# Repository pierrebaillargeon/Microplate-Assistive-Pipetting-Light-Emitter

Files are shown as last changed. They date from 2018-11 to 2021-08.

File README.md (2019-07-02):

# Microplate Assistive Pipetting Light Emitter

The contents of this repository represent the design files and code needed to reproduce the electronics, firmware and GUI interface for the Microplate Assistive Pipetting Light Emitter. 

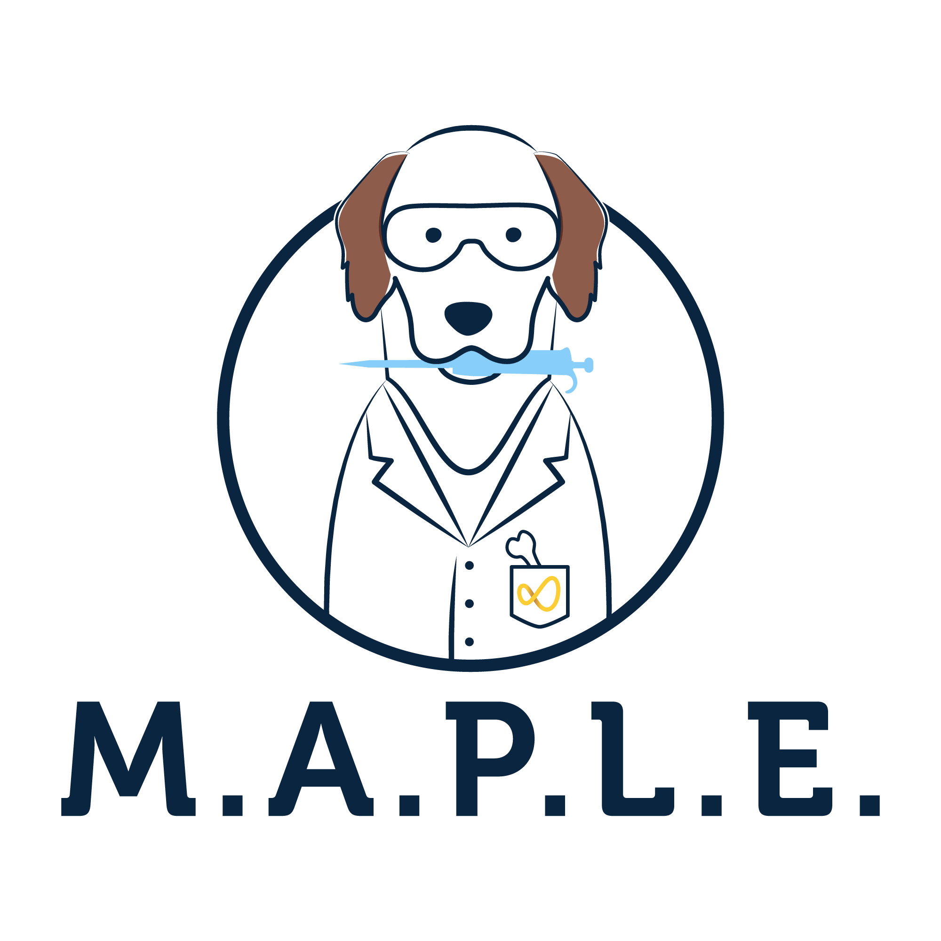
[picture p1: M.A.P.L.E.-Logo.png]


A manuscript describing the design and usage of this light guide has been published in the <A href="https://journals.sagepub.com/doi/full/10.1177/2472630318822476">SLAS Technology journal</A> and presented at SLAS 2019 as part of a presentation titled <A href="https://www.pathlms.com/slas/courses/10547/video_presentations/127546">'A longitudinal analysis over 10 years of enabling technologies for early drug discovery using open source tools'</a>.

If you are interested in purchasing preassembled illumination panels, as opposed to assembling them by hand, they are available on the <a href="https://www.tindie.com/stores/Maplebear/">Maplebear Electronics Tindie store</a>.

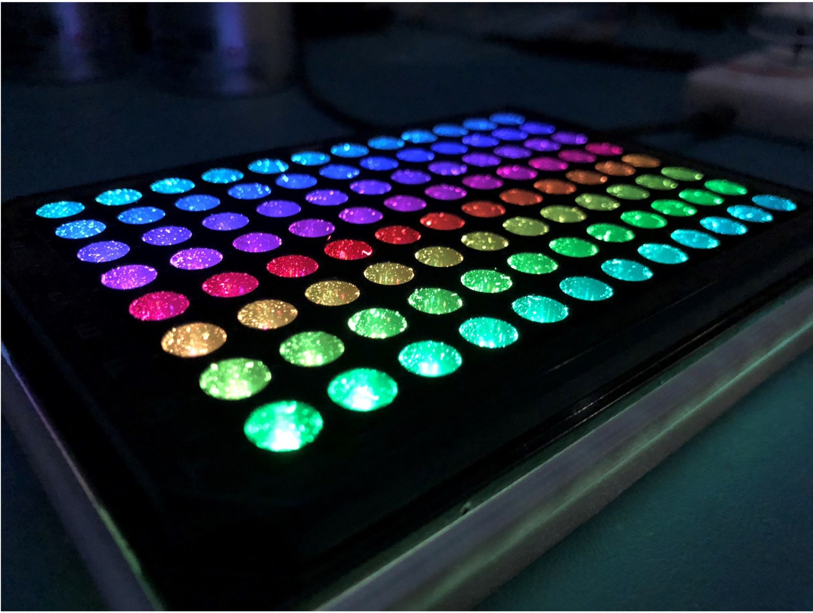
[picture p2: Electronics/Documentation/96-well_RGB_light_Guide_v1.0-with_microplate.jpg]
<A href="https://raw.githubusercontent.com/pierrebaillargeon/Microplate-Assistive-Pipetting-Light-Emitter/master/Electronics/Documentation/96-well_RGB_light_Guide_v1.0-with_m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"></a>
  
<A href="https://raw.githubusercontent.com/pierrebaillargeon/Microplate-Assistive-Pipetting-Light-Emitter/master/Electronics/Documentation/96-well_RGB_light_guide_v1.3-protot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"></a>
  
<A href="https://raw.githubusercontent.com/pierrebaillargeon/Microplate-Assistive-Pipetting-Light-Emitter/master/Electronics/Documentation/384-well_RGB_light_guide_v1.1.png"></a>

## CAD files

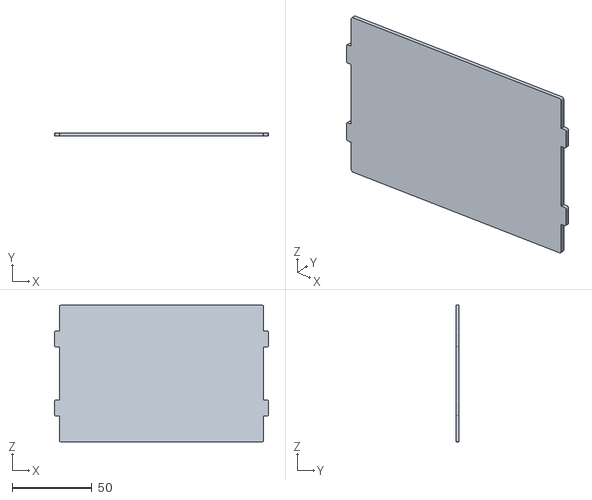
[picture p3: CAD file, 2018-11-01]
CAD/clear-cover.stl
133.8 x 2.00 x 85.5

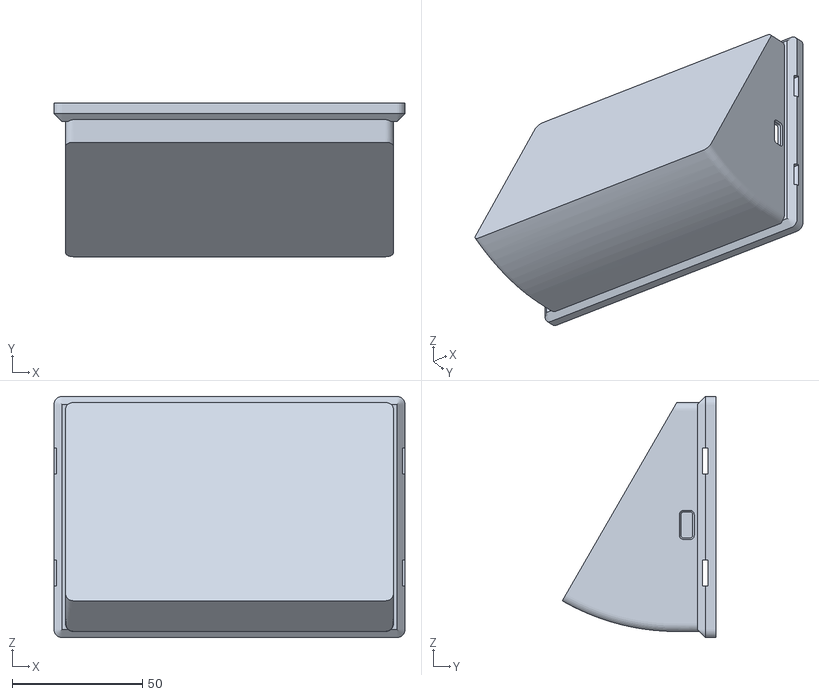
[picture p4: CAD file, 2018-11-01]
CAD/Gen 2 enclosure/30 degree RGB enclosure v2.1.stl
134.9 x 59.0 x 92.6

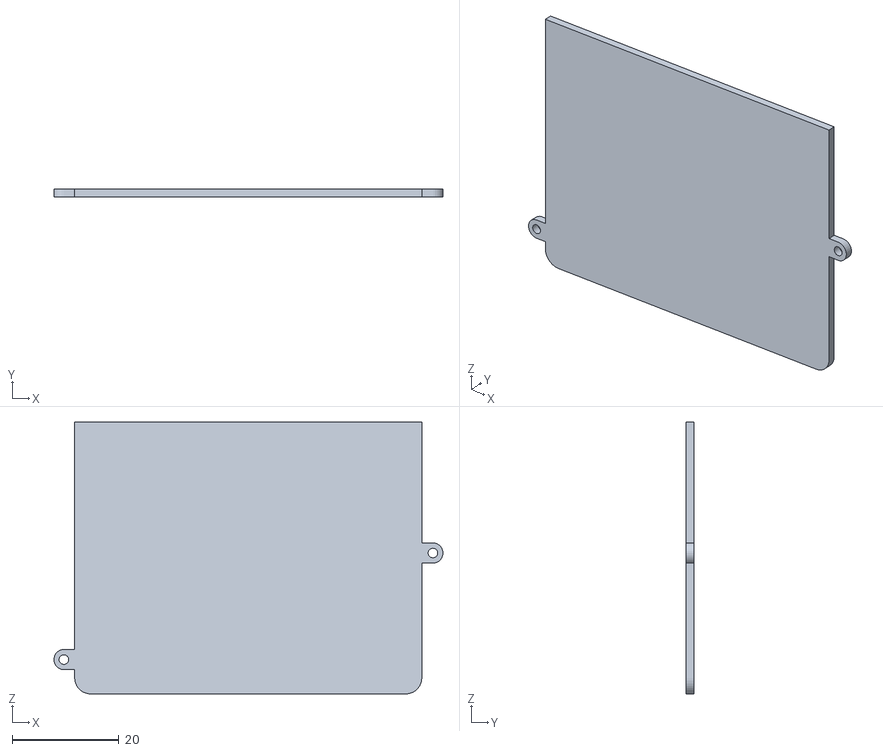
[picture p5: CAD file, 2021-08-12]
CAD/Portable enclosure/Battery lid.stl
72.8 x 1.50 x 50.9

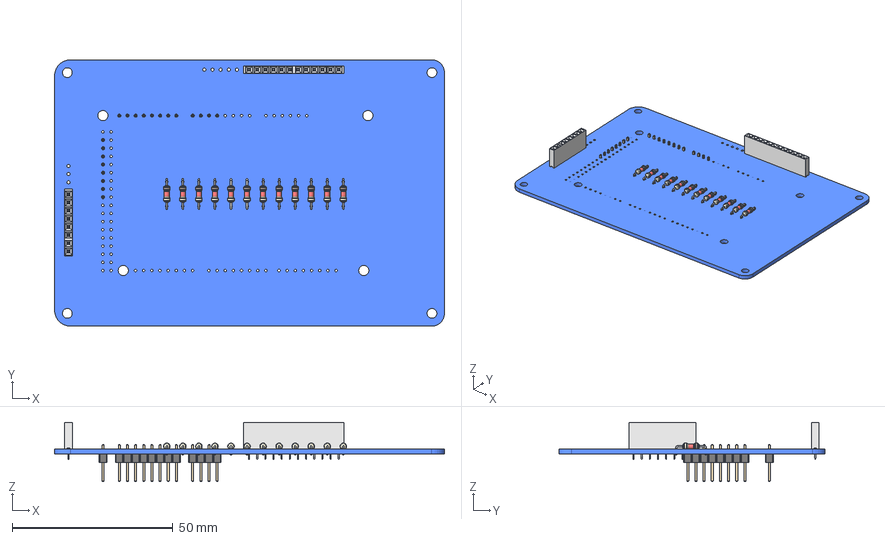
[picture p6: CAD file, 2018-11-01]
Electronics/LED Matrix - 96 well adapter board for Arduino mega/96 well adapter board for Arduino mega1.step
121.5 x 83.0 x 18.4 mm
Pcb
Socket_Strip_Straight_1x12_Pitch2.54mm_
Socket_Strip_Straight_1x08_Pitch2.54mm_
Actual_resistor_
Actual_resistor_001
Actual_resistor_002
Actual_resistor_003
Actual_resistor_004
Actual_resistor_005
Actual_resistor_006
Actual_resistor_007
Actual_resistor_008
Actual_resistor_009
Actual_resistor_010
Actual_resistor_011
Pin_Header_Straight_1x08_Pitch254mm_
Pin_Header_Straight_1x08_Pitch254mm_001
Pin_Header_Straight_1x04_Pitch254mm_

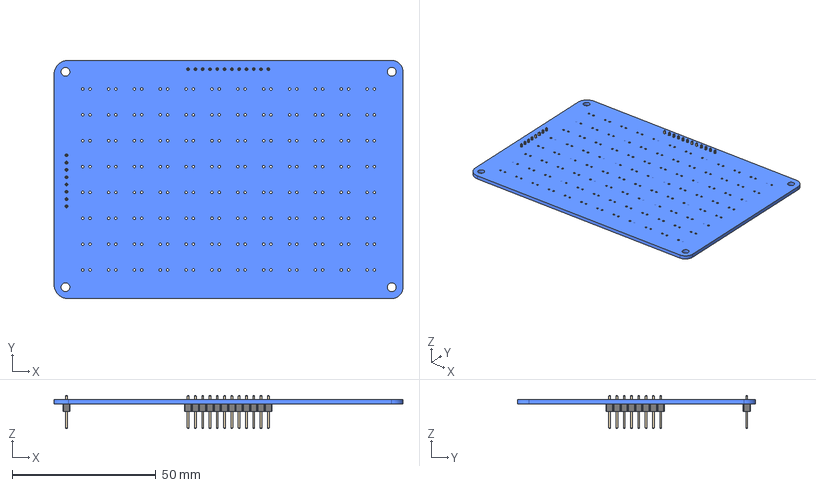
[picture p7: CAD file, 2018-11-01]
Electronics/LED Matrix - 96 well/LED Matrix1.step
121.5 x 83.0 x 11.5 mm
Pcb
Pin_Header_Straight_1x12_Pitch254mm_
Pin_Header_Straight_1x08_Pitch254mm_

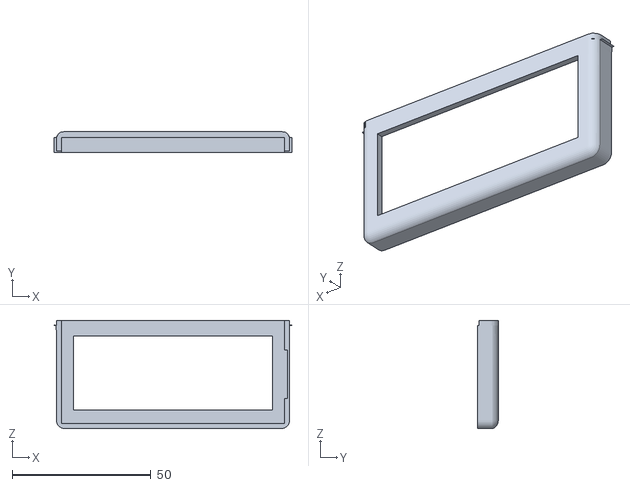
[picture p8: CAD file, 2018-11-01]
CAD/Gen 2 enclosure/LCD cover for enclosure v2.0.stl
85.7 x 7.41 x 38.9

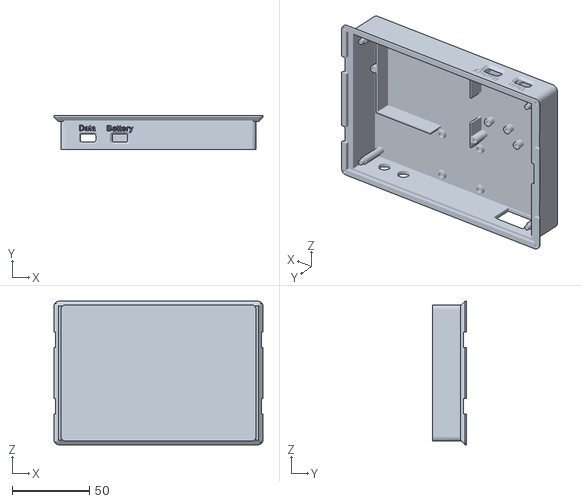
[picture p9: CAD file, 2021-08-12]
CAD/Portable enclosure/Enclosure.stl
134.9 x 22.0 x 92.6

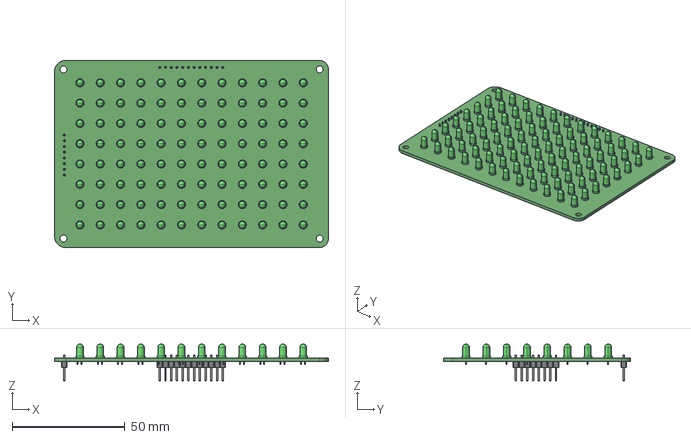
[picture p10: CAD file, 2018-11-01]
Electronics/LED Matrix - 96 well/LED Matrix.step
121.5 x 83.0 x 16.4 mm

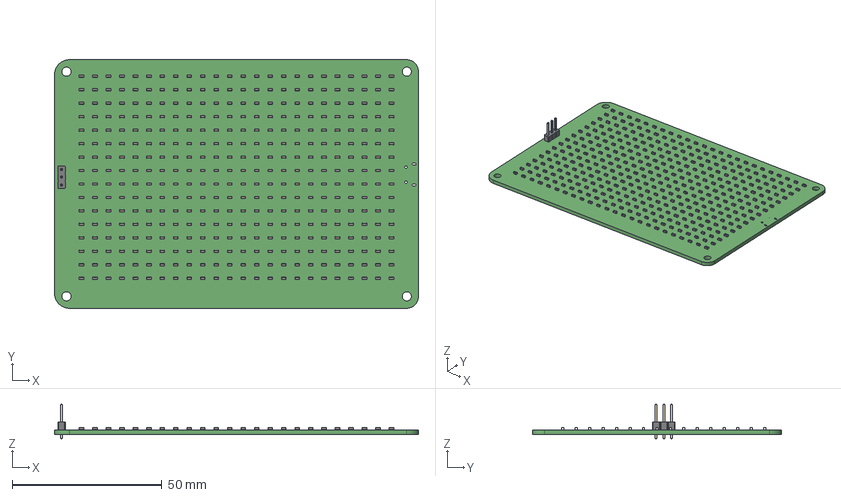
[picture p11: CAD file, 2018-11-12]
Electronics/Neopixel - 384 well/Neopixel nano - 384 well v2.step
121.5 x 83.0 x 11.5 mm

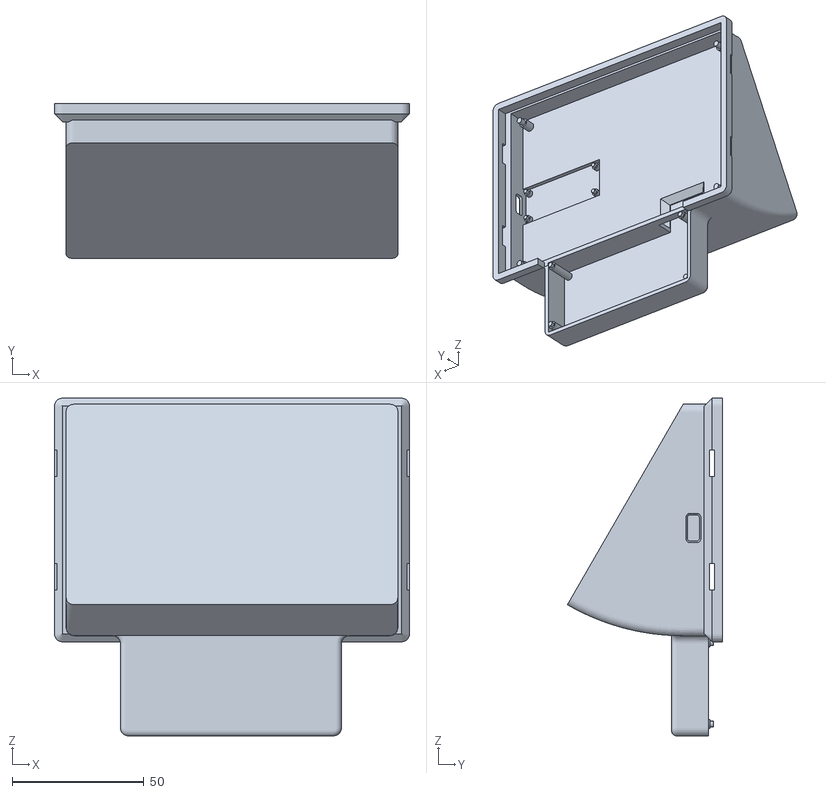
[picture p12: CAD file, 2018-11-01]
CAD/Gen 2 enclosure/Enclosure v2.0 with LCD.stl
134.9 x 59.0 x 128.4

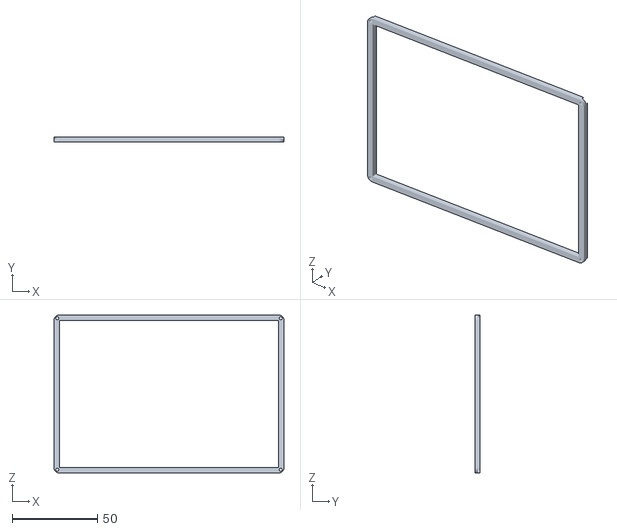
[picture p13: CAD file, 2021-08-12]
CAD/Portable enclosure/Enclosure top lid.stl
134.9 x 3.00 x 92.6

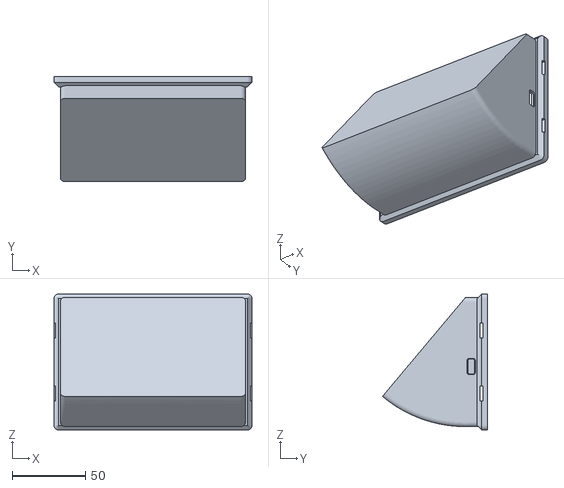
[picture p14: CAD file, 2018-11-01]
CAD/Gen 2 enclosure/40 degree RGB enclosure v2.1.stl
134.9 x 71.6 x 92.6

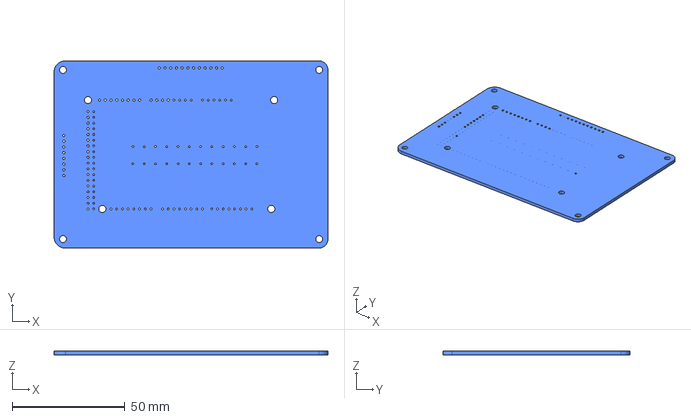
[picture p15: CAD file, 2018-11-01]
Electronics/LED Matrix - 96 well adapter board for Arduino mega/Pcb.step
121.5 x 83.0 x 1.60 mm

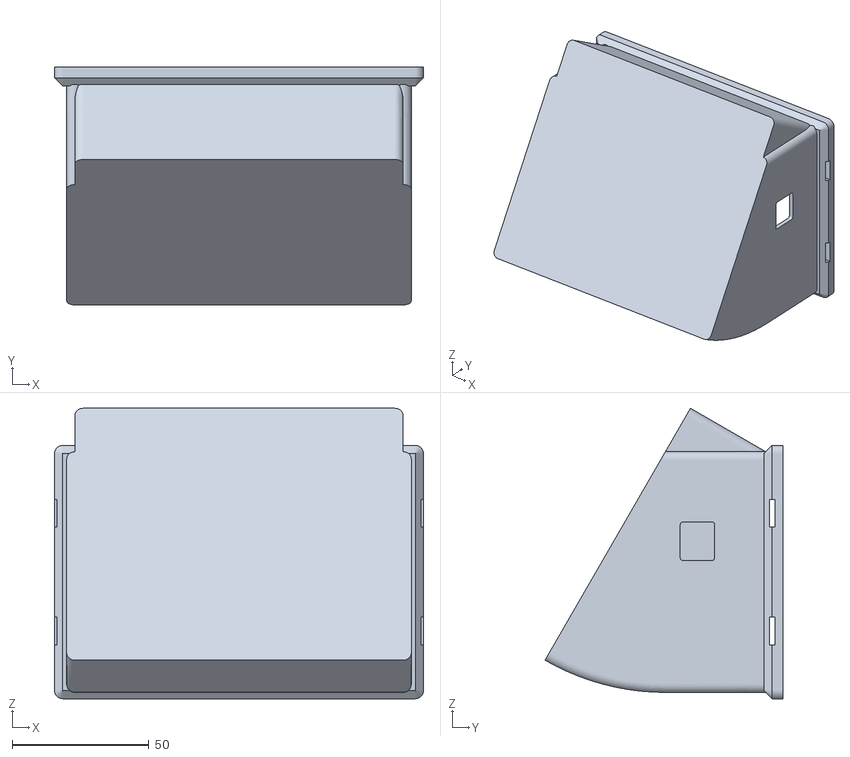
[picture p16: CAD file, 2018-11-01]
CAD/Gen 2 enclosure/30 degree Enclosure v2.1.stl
134.9 x 87.0 x 106.2

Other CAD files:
Electronics/Neopixel - 384 well/Neopixel nano - 384 well.step
Electronics/Neopixel - 96 well/Neopixel mini - 96 well.step
Electronics/LED Matrix - 96 well adapter board for Arduino mega/_6_well_adapter_board_for_Arduino_mega1.FCStd
Electronics/LED Matrix - 96 well adapter board for Arduino mega/_6_well_adapter_board_for_Arduino_mega.FCStd
CAD/Gen 1 enclosure/Enclosure v2.1.stl
CAD/Portable enclosure/PortableEnclosure.f3z
Electronics/LED Matrix - 96 well/LED_Matrix.FCStd
Electronics/LED Matrix - 96 well/LED_Matrix1.FCStd

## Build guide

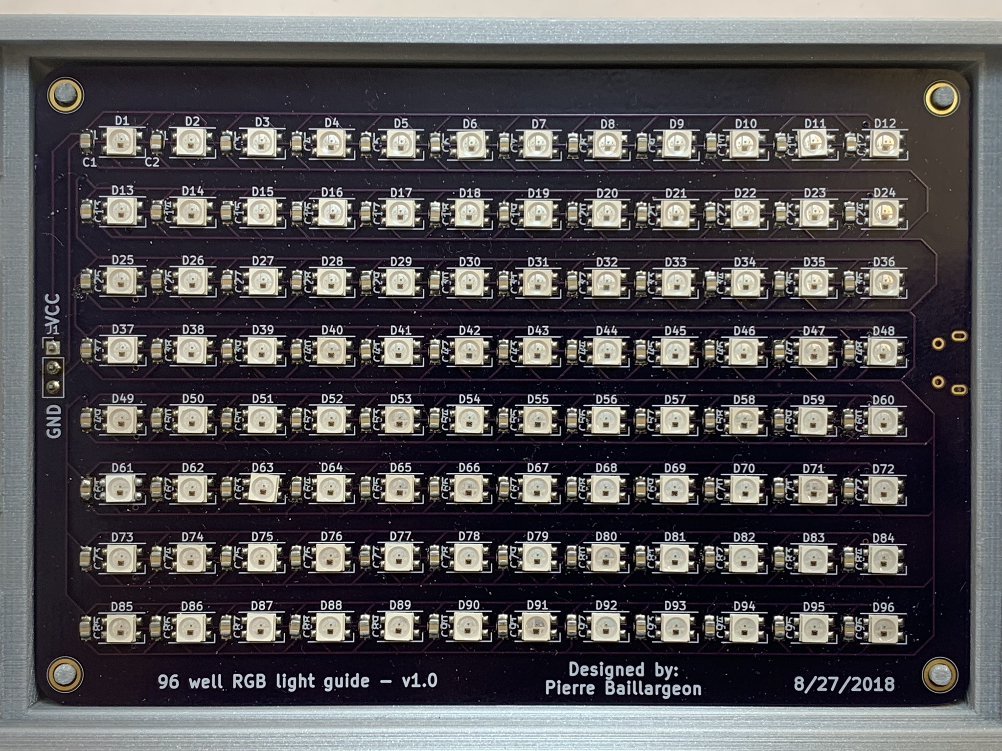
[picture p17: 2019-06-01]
Electronics/Documentation/96-well_RGB_light_guide_v1.0-prototype_PCB.jpg

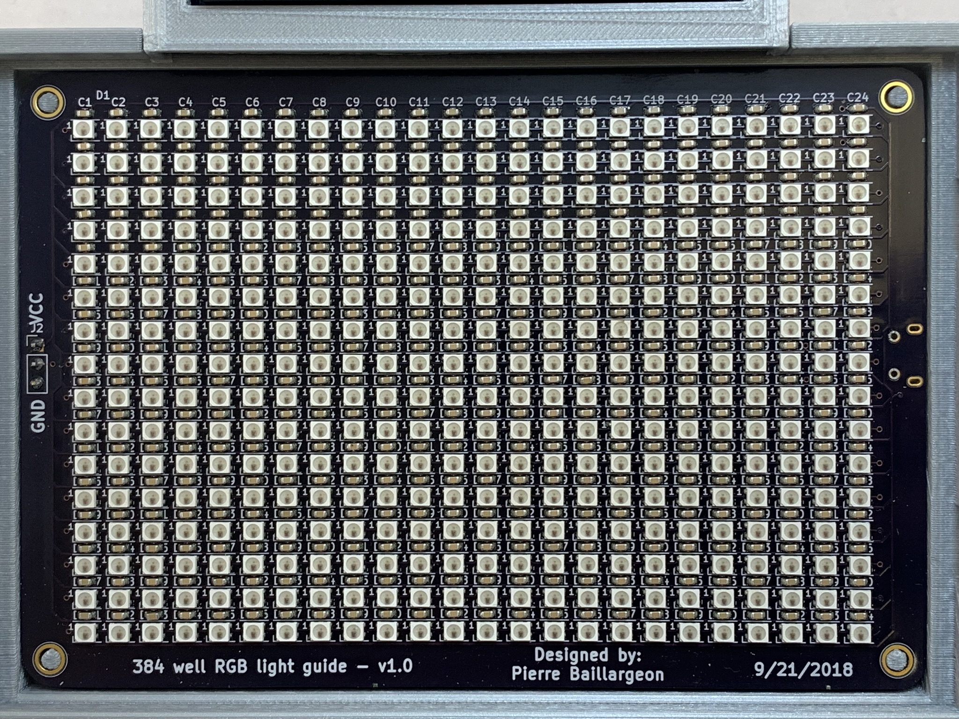
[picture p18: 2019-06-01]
Electronics/Documentation/384-well_RGB_light_guide_v1.0-prototype_PCB.jpg

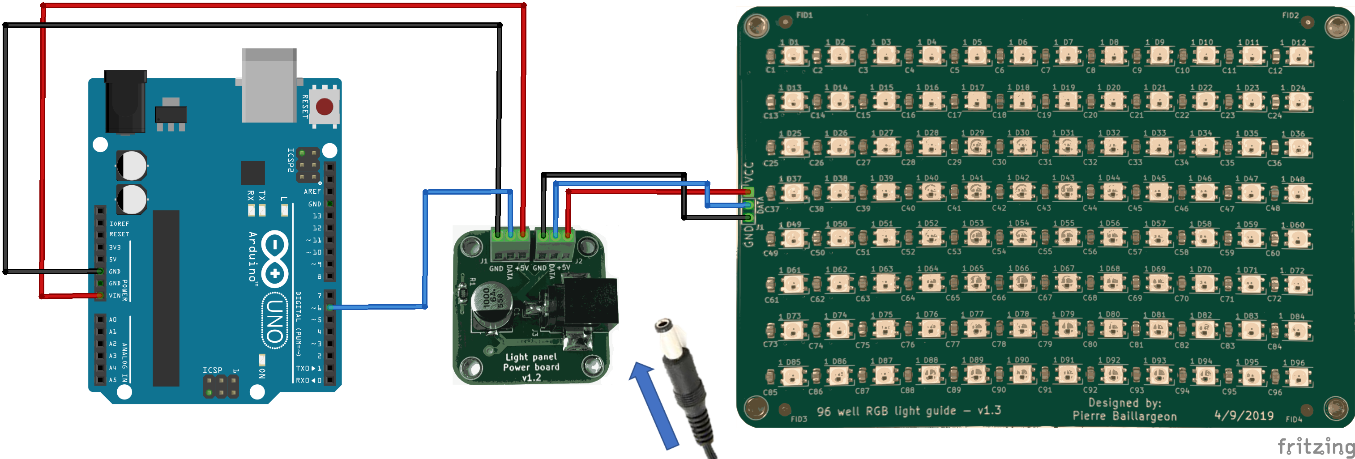
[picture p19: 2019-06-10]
Electronics/Documentation/96-well-rgb-light-guide-wiring-example.png

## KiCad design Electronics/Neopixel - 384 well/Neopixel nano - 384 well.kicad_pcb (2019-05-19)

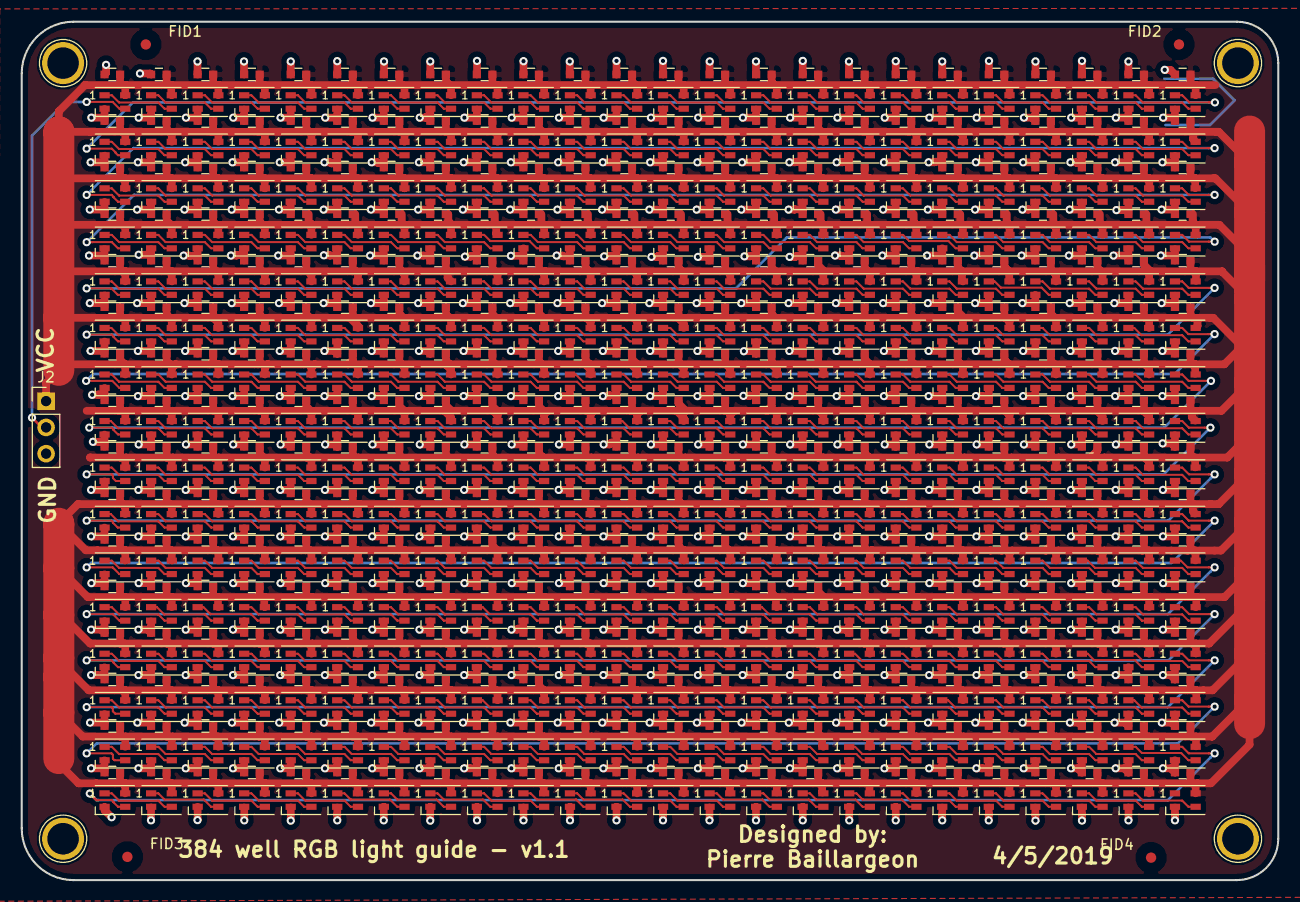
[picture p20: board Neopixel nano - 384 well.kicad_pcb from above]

Board: 2 copper layers, 121.5 x 83.0 mm, 773 parts (0 on the bottom side), 386 nets.

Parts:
C1, C2, C3, C4, C5, C6, C7, C8, C9, C10, C11, C12, C13, C14, C15, C16, C17, C18, C19, C20, C21, C22, C23, C24, C25, C26, C27, C28, C29, C30, C31, C32, C33, C34, C35, C36, C37, C38, C39, C40, C41, C42, C43, C44, C45, C46, C47, C48, C49, C50, C51, C52, C53, C54, C55, C56, C57, C58, C59, C60, C61, C62, C63, C64, C65, C66, C67, C68, C69, C70, C71, C72, C73, C74, C75, C76, C77, C78, C79, C80, C81, C82, C83, C84, C85, C86, C87, C88, C89, C90, C91, C92, C93, C94, C95, C96, C97, C98, C99, C100, C101, C102, C103, C104, C105, C106, C107, C108, C109, C110, C111, C112, C113, C114, C115, C116, C117, C118, C119, C120, C121, C122, C123, C124, C125, C126, C127, C128, C129, C130, C131, C132, C133, C134, C135, C136, C137, C138, C139, C140, C141, C142, C143, C144, C145, C146, C147, C148, C149, C150, C151, C152, C153, C154, C155, C156, C157, C158, C159, C160, C161, C162, C163, C164, C165, C166, C167, C168, C169, C170, C171, C172, C173, C174, C175, C176, C177, C178, C179, C180, C181, C182, C183, C184, C185, C186, C187, C188, C189, C190, C191, C192, C193, C194, C195, C196, C197, C198, C199, C200, C201, C202, C203, C204, C205, C206, C207, C208, C209, C210, C211, C212, C213, C214, C215, C216, C217, C218, C219, C220, C221, C222, C223, C224, C225, C226, C227, C228, C229, C230, C231, C232, C233, C234, C235, C236, C237, C238, C239, C240, C241, C242, C243, C244, C245, C246, C247, C248, C249, C250, C251, C252, C253, C254, C255, C256, C257, C258, C259, C260, C261, C262, C263, C264, C265, C266, C267, C268, C269, C270, C271, C272, C273, C274, C275, C276, C277, C278, C279, C280, C281, C282, C283, C284, C285, C286, C287, C288, C289, C290, C291, C292, C293, C294, C295, C296, C297, C298, C299, C300, C301, C302, C303, C304, C305, C306, C307, C308, C309, C310, C311, C312, C313, C314, C315, C316, C317, C318, C319, C320, C321, C322, C323, C324, C325, C326, C327, C328, C329, C330, C331, C332, C333, C334, C335, C336, C337, C338, C339, C340, C341, C342, C343, C344, C345, C346, C347, C348, C349, C350, C351, C352, C353, C354, C355, C356, C357, C358, C359, C360, C361, C362, C363, C364, C365, C366, C367, C368, C369, C370, C371, C372, C373, C374, C375, C376, C377, C378, C379, C380, C381, C382, C383, C384: CAP; C_0603
D1, D2, D3, D4, D5, D6, D7, D8, D9, D10, D11, D12, D13, D14, D15, D16, D17, D18, D19, D20, D21, D22, D23, D24, D25, D26, D27, D28, D29, D30, D31, D32, D33, D34, D35, D36, D37, D38, D39, D40, D41, D42, D43, D44, D45, D46, D47, D48, D49, D50, D51, D52, D53, D54, D55, D56, D57, D58, D59, D60, D61, D62, D63, D64, D65, D66, D67, D68, D69, D70, D71, D72, D73, D74, D75, D76, D77, D78, D79, D80, D81, D82, D83, D84, D85, D86, D87, D88, D89, D90, D91, D92, D93, D94, D95, D96, D97, D98, D99, D100, D101, D102, D103, D104, D105, D106, D107, D108, D109, D110, D111, D112, D113, D114, D115, D116, D117, D118, D119, D120, D121, D122, D123, D124, D125, D126, D127, D128, D129, D130, D131, D132, D133, D134, D135, D136, D137, D138, D139, D140, D141, D142, D143, D144, D145, D146, D147, D148, D149, D150, D151, D152, D153, D154, D155, D156, D157, D158, D159, D160, D161, D162, D163, D164, D165, D166, D167, D168, D169, D170, D171, D172, D173, D174, D175, D176, D177, D178, D179, D180, D181, D182, D183, D184, D185, D186, D187, D188, D189, D190, D191, D192, D193, D194, D195, D196, D197, D198, D199, D200, D201, D202, D203, D204, D205, D206, D207, D208, D209, D210, D211, D212, D213, D214, D215, D216, D217, D218, D219, D220, D221, D222, D223, D224, D225, D226, D227, D228, D229, D230, D231, D232, D233, D234, D235, D236, D237, D238, D239, D240, D241, D242, D243, D244, D245, D246, D247, D248, D249, D250, D251, D252, D253, D254, D255, D256, D257, D258, D259, D260, D261, D262, D263, D264, D265, D266, D267, D268, D269, D270, D271, D272, D273, D274, D275, D276, D277, D278, D279, D280, D281, D282, D283, D284, D285, D286, D287, D288, D289, D290, D291, D292, D293, D294, D295, D296, D297, D298, D299, D300, D301, D302, D303, D304, D305, D306, D307, D308, D309, D310, D311, D312, D313, D314, D315, D316, D317, D318, D319, D320, D321, D322, D323, D324, D325, D326, D327, D328, D329, D330, D331, D332, D333, D334, D335, D336, D337, D338, D339, D340, D341, D342, D343, D344, D345, D346, D347, D348, D349, D350, D351, D352, D353, D354, D355, D356, D357, D358, D359, D360, D361, D362, D363, D364, D365, D366, D367, D368, D369, D370, D371, D372, D373, D374, D375, D376, D377, D378, D379, D380, D381, D382, D383, D384: SK6805; LED_SK6805_PLCC4_2.4x2.7mm_P1.3mm
FID1, FID2, FID3, FID4: Fiducial_1mm_Mask3mm
J2: Conn_01x03_Male; Pin_Header_Straight_1x03_Pitch2.54mm

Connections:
GND: C1.2, C2.2, C3.2, C4.2, C5.2, C6.2, C7.2, C8.2, C9.2, C10.2, C11.2, C12.2, C13.2, C14.2, C15.2, C16.2, C17.2, C18.2, C19.2, C20.2, C21.2, C22.2, C23.2, C24.2, C25.2, C26.2, C27.2, C28.2, C29.2, C30.2, C31.2, C32.2, C33.2, C34.2, C35.2, C36.2, C37.2, C38.2, C39.2, C40.2, C41.2, C42.2, C43.2, C44.2, C45.2, C46.2, C47.2, C48.2, C49.2, C50.2, C51.2, C52.2, C53.2, C54.2, C55.2, C56.2, C57.2, C58.2, C59.2, C60.2, C61.2, C62.2, C63.2, C64.2, C65.2, C66.2, C67.2, C68.2, C69.2, C70.2, C71.2, C72.2, C73.2, C74.2, C75.2, C76.2, C77.2, C78.2, C79.2, C80.2, C81.2, C82.2, C83.2, C84.2, C85.2, C86.2, C87.2, C88.2, C89.2, C90.2, C91.2, C92.2, C93.2, C94.2, C95.2, C96.2, C97.2, C98.2, C99.2, C100.2, C101.2, C102.2, C103.2, C104.2, C105.2, C106.2, C107.2, C108.2, C109.2, C110.2, C111.2, C112.2, C113.2, C114.2, C115.2, C116.2, C117.2, C118.2, C119.2, C120.2, C121.2, C122.2, C123.2, C124.2, C125.2, C126.2, C127.2, C128.2, C129.2, C130.2, C131.2, C132.2, C133.2, C134.2, C135.2, C136.2, C137.2, C138.2, C139.2, C140.2, C141.2, C142.2, C143.2, C144.2, C145.2, C146.2, C147.2, C148.2, C149.2, C150.2, C151.2, C152.2, C153.2, C154.2, C155.2, C156.2, C157.2, C158.2, C159.2, C160.2, C161.2, C162.2, C163.2, C164.2, C165.2, C166.2, C167.2, C168.2, C169.2, C170.2, C171.2, C172.2, C173.2, C174.2, C175.2, C176.2, C177.2, C178.2, C179.2, C180.2, C181.2, C182.2, C183.2, C184.2, C185.2, C186.2, C187.2, C188.2, C189.2, C190.2, C191.2, C192.2, C193.2, C194.2, C195.2, C196.2, C197.2, C198.2, C199.2, C200.2, C201.2, C202.2, C203.2, C204.2, C205.2, C206.2, C207.2, C208.2, C209.2, C210.2, C211.2, C212.2, C213.2, C214.2, C215.2, C216.2, C217.2, C218.2, C219.2, C220.2, C221.2, C222.2, C223.2, C224.2, C225.2, C226.2, C227.2, C228.2, C229.2, C230.2, C231.2, C232.2, C233.2, C234.2, C235.2, C236.2, C237.2, C238.2, C239.2, C240.2, C241.2, C242.2, C243.2, C244.2, C245.2, C246.2, C247.2, C248.2, C249.2, C250.2, C251.2, C252.2, C253.2, C254.2, C255.2, C256.2, C257.2, C258.2, C259.2, C260.2, C261.2, C262.2, C263.2, C264.2, C265.2, C266.2, C267.2, C268.2, C269.2, C270.2, C271.2, C272.2, C273.2, C274.2, C275.2, C276.2, C277.2, C278.2, C279.2, C280.2, C281.2, C282.2, C283.2, C284.2, C285.2, C286.2, C287.2, C288.2, C289.2, C290.2, C291.2, C292.2, C293.2, C294.2, C295.2, C296.2, C297.2, C298.2, C299.2, C300.2, C301.2, C302.2, C303.2, C304.2, C305.2, C306.2, C307.2, C308.2, C309.2, C310.2, C311.2, C312.2, C313.2, C314.2, C315.2, C316.2, C317.2, C318.2, C319.2, C320.2, C321.2, C322.2, C323.2, C324.2, C325.2, C326.2, C327.2, C328.2, C329.2, C330.2, C331.2, C332.2, C333.2, C334.2, C335.2, C336.2, C337.2, C338.2, C339.2, C340.2, C341.2, C342.2, C343.2, C344.2, C345.2, C346.2, C347.2, C348.2, C349.2, C350.2, C351.2, C352.2, C353.2, C354.2, C355.2, C356.2, C357.2, C358.2, C359.2, C360.2, C361.2, C362.2, C363.2, C364.2, C365.2, C366.2, C367.2, C368.2, C369.2, C370.2, C371.2, C372.2, C373.2, C374.2, C375.2, C376.2, C377.2, C378.2, C379.2, C380.2, C381.2, C382.2, C383.2, C384.2, D1.2, D2.2, D3.2, D4.2, D5.2, D6.2, D7.2, D8.2, D9.2, D10.2, D11.2, D12.2, D13.2, D14.2, D15.2, D16.2, D17.2, D18.2, D19.2, D20.2, D21.2, D22.2, D23.2, D24.2, D25.2, D26.2, D27.2, D28.2, D29.2, D30.2, D31.2, D32.2, D33.2, D34.2, D35.2, D36.2, D37.2, D38.2, D39.2, D40.2, D41.2, D42.2, D43.2, D44.2, D45.2, D46.2, D47.2, D48.2, D49.2, D50.2, D51.2, D52.2, D53.2, D54.2, D55.2, D56.2, D57.2, D58.2, D59.2, D60.2, D61.2, D62.2, D63.2, D64.2, D65.2, D66.2, D67.2, D68.2, D69.2, D70.2, D71.2, D72.2, D73.2, D74.2, D75.2, D76.2, D77.2, D78.2, D79.2, D80.2, D81.2, D82.2, D83.2, D84.2, D85.2, D86.2, D87.2, D88.2, D89.2, D90.2, D91.2, D92.2, D93.2, D94.2, D95.2, D96.2, D97.2, D98.2, D99.2, D100.2, D101.2, D102.2, D103.2, D104.2, D105.2, D106.2, D107.2, D108.2, D109.2, D110.2, D111.2, D112.2, D113.2, D114.2, D115.2, D116.2, D117.2, D118.2, D119.2, D120.2, D121.2, D122.2, D123.2, D124.2, D125.2, D126.2, D127.2, D128.2, D129.2, D130.2, D131.2, D132.2, D133.2, D134.2, D135.2, D136.2, D137.2, D138.2, D139.2, D140.2, D141.2, D142.2, D143.2, D144.2, D145.2, D146.2, D147.2, D148.2, D149.2, D150.2, D151.2, D152.2, D153.2, D154.2, D155.2, D156.2, D157.2, D158.2, D159.2, D160.2, D161.2, D162.2, D163.2, D164.2, D165.2, D166.2, D167.2, D168.2, D169.2, D170.2, D171.2, D172.2, D173.2, D174.2, D175.2, D176.2, D177.2, D178.2, D179.2, D180.2, D181.2, D182.2, D183.2, D184.2, D185.2, D186.2, D187.2, D188.2, D189.2, D190.2, D191.2, D192.2, D193.2, D194.2, D195.2, D196.2, D197.2, D198.2, D199.2, D200.2, D201.2, D202.2, D203.2, D204.2, D205.2, D206.2, D207.2, D208.2, D209.2, D210.2, D211.2, D212.2, D213.2, D214.2, D215.2, D216.2, D217.2, D218.2, D219.2, D220.2, D221.2, D222.2, D223.2, D224.2, D225.2, D226.2, D227.2, D228.2, D229.2, D230.2, D231.2, D232.2, D233.2, D234.2, D235.2, D236.2, D237.2, D238.2, D239.2, D240.2, D241.2, D242.2, D243.2, D244.2, D245.2, D246.2, D247.2, D248.2, D249.2, D250.2, D251.2, D252.2, D253.2, D254.2, D255.2, D256.2, D257.2, D258.2, D259.2, D260.2, D261.2, D262.2, D263.2, D264.2, D265.2, D266.2, D267.2, D268.2, D269.2, D270.2, D271.2, D272.2, D273.2, D274.2, D275.2, D276.2, D277.2, D278.2, D279.2, D280.2, D281.2, D282.2, D283.2, D284.2, D285.2, D286.2, D287.2, D288.2, D289.2, D290.2, D291.2, D292.2, D293.2, D294.2, D295.2, D296.2, D297.2, D298.2, D299.2, D300.2, D301.2, D302.2, D303.2, D304.2, D305.2, D306.2, D307.2, D308.2, D309.2, D310.2, D311.2, D312.2, D313.2, D314.2, D315.2, D316.2, D317.2, D318.2, D319.2, D320.2, D321.2, D322.2, D323.2, D324.2, D325.2, D326.2, D327.2, D328.2, D329.2, D330.2, D331.2, D332.2, D333.2, D334.2, D335.2, D336.2, D337.2, D338.2, D339.2, D340.2, D341.2, D342.2, D343.2, D344.2, D345.2, D346.2, D347.2, D348.2, D349.2, D350.2, D351.2, D352.2, D353.2, D354.2, D355.2, D356.2, D357.2, D358.2, D359.2, D360.2, D361.2, D362.2, D363.2, D364.2, D365.2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
unnamed: D1.1, D2.3
unnamed: D1.3, J2.2
unnamed: D2.1, D3.3
unnamed: D3.1, D4.3
unnamed: D4.1, D5.3
unnamed: D5.1, D6.3
unnamed: D6.1, D7.3
unnamed: D7.1, D8.3
unnamed: D8.1, D9.3
unnamed: D10.1, D11.3
unnamed: D9.1, D10.3
unnamed: D11.1, D12.3
unnamed: D12.1, D13.3
unnamed: D13.1, D14.3
unnamed: D14.1, D15.3
unnamed: D15.1, D16.3
unnamed: D16.1, D17.3
unnamed: D17.1, D18.3
unnamed: D18.1, D19.3
unnamed: D19.1, D20.3
unnamed: D20.1, D21.3
unnamed: D21.1, D22.3
unnamed: D22.1, D23.3
unnamed: D23.1, D24.3
unnamed: D24.1, D25.3
unnamed: D25.1, D26.3
unnamed: D26.1, D27.3
unnamed: D27.1, D28.3
unnamed: D28.1, D29.3
unnamed: D29.1, D30.3
unnamed: D30.1, D31.3
unnamed: D31.1, D32.3
unnamed: D32.1, D33.3
unnamed: D33.1, D34.3
unnamed: D34.1, D35.3
unnamed: D35.1, D36.3
unnamed: D36.1, D37.3
unnamed: D37.1, D38.3
unnamed: D38.1, D39.3
unnamed: D39.1, D40.3
unnamed: D40.1, D41.3
unnamed: D41.1, D42.3
unnamed: D42.1, D43.3
unnamed: D43.1, D44.3
unnamed: D44.1, D45.3
unnamed: D45.1, D46.3
unnamed: D46.1, D47.3
unnamed: D47.1, D48.3
unnamed: D48.1, D49.3
unnamed: D49.1, D50.3
unnamed: D50.1, D51.3
unnamed: D51.1, D52.3
unnamed: D52.1, D53.3
unnamed: D53.1, D54.3
unnamed: D54.1, D55.3
unnamed: D55.1, D56.3
unnamed: D56.1, D57.3
unnamed: D57.1, D58.3
unnamed: D58.1, D59.3
unnamed: D59.1, D60.3
unnamed: D60.1, D61.3
unnamed: D61.1, D62.3
unnamed: D62.1, D63.3
unnamed: D63.1, D64.3
unnamed: D64.1, D65.3
unnamed: D65.1, D66.3
unnamed: D66.1, D67.3
unnamed: D67.1, D68.3
unnamed: D68.1, D69.3
unnamed: D69.1, D70.3
unnamed: D70.1, D71.3
unnamed: D71.1, D72.3
unnamed: D72.1, D73.3
unnamed: D73.1, D74.3
unnamed: D74.1, D75.3
unnamed: D75.1, D76.3
unnamed: D76.1, D77.3
unnamed: D77.1, D78.3
unnamed: D78.1, D79.3
unnamed: D79.1, D80.3
unnamed: D80.1, D81.3
unnamed: D81.1, D82.3
unnamed: D82.1, D83.3
unnamed: D83.1, D84.3
unnamed: D84.1, D85.3
unnamed: D85.1, D86.3
unnamed: D86.1, D87.3
unnamed: D87.1, D88.3
unnamed: D88.1, D89.3
unnamed: D89.1, D90.3
unnamed: D90.1, D91.3
unnamed: D91.1, D92.3
unnamed: D92.1, D93.3
unnamed: D93.1, D94.3
unnamed: D94.1, D95.3
unnamed: D95.1, D96.3
unnamed: D96.1, D97.3
unnamed: D97.1, D98.3
unnamed: D98.1, D99.3
unnamed: D100.1, D101.3
unnamed: D99.1, D100.3
unnamed: D101.1, D102.3
unnamed: D102.1, D103.3
unnamed: D103.1, D104.3
unnamed: D104.1, D105.3
unnamed: D105.1, D106.3
unnamed: D106.1, D107.3
unnamed: D107.1, D108.3
unnamed: D108.1, D109.3
unnamed: D109.1, D110.3
unnamed: D110.1, D111.3
unnamed: D111.1, D112.3
unnamed: D112.1, D113.3
unnamed: D113.1, D114.3
unnamed: D114.1, D115.3
unnamed: D115.1, D116.3
unnamed: D116.1, D117.3
unnamed: D117.1, D118.3
unnamed: D118.1, D119.3
unnamed: D119.1, D120.3
unnamed: D120.1, D121.3
unnamed: D121.1, D122.3
unnamed: D122.1, D123.3
unnamed: D123.1, D124.3
unnamed: D124.1, D125.3
unnamed: D125.1, D126.3
unnamed: D126.1, D127.3
unnamed: D127.1, D128.3
unnamed: D128.1, D129.3
unnamed: D129.1, D130.3
unnamed: D130.1, D131.3
unnamed: D131.1, D132.3
unnamed: D132.1, D133.3
unnamed: D133.1, D134.3
unnamed: D134.1, D135.3
unnamed: D135.1, D136.3
unnamed: D136.1, D137.3
unnamed: D137.1, D138.3
unnamed: D138.1, D139.3
unnamed: D139.1, D140.3
unnamed: D140.1, D141.3
unnamed: D141.1, D142.3
unnamed: D142.1, D143.3
unnamed: D143.1, D144.3
unnamed: D144.1, D145.3
unnamed: D145.1, D146.3
unnamed: D146.1, D147.3
unnamed: D147.1, D148.3
unnamed: D148.1, D149.3
unnamed: D149.1, D150.3
unnamed: D150.1, D151.3
unnamed: D151.1, D152.3
unnamed: D152.1, D153.3
unnamed: D153.1, D154.3
unnamed: D154.1, D155.3
unnamed: D155.1, D156.3
unnamed: D156.1, D157.3
unnamed: D157.1, D158.3
unnamed: D158.1, D159.3
unnamed: D159.1, D160.3
unnamed: D160.1, D161.3
unnamed: D161.1, D162.3
unnamed: D162.1, D163.3
unnamed: D163.1, D164.3
unnamed: D164.1, D165.3
unnamed: D165.1, D166.3
unnamed: D166.1, D167.3
unnamed: D167.1, D168.3
unnamed: D168.1, D169.3
unnamed: D169.1, D170.3
unnamed: D170.1, D171.3
unnamed: D171.1, D172.3
unnamed: D172.1, D173.3
unnamed: D173.1, D174.3
unnamed: D174.1, D175.3
unnamed: D175.1, D176.3
unnamed: D176.1, D177.3
unnamed: D177.1, D178.3
unnamed: D178.1, D179.3
unnamed: D179.1, D180.3
unnamed: D180.1, D181.3
unnamed: D181.1, D182.3
unnamed: D182.1, D183.3
unnamed: D183.1, D184.3
unnamed: D184.1, D185.3
unnamed: D185.1, D186.3
unnamed: D186.1, D187.3
unnamed: D187.1, D188.3
unnamed: D188.1, D189.3
unnamed: D189.1, D190.3
unnamed: D190.1, D191.3
unnamed: D191.1, D192.3
unnamed: D192.1, D193.3
unnamed: D193.1, D194.3
unnamed: D194.1, D195.3
unnamed: D195.1, D196.3
unnamed: D196.1, D197.3
unnamed: D197.1, D198.3
unnamed: D198.1, D199.3
unnamed: D199.1, D200.3
unnamed: D200.1, D201.3
unnamed: D201.1, D202.3
unnamed: D202.1, D203.3
unnamed: D203.1, D204.3
unnamed: D204.1, D205.3
unnamed: D205.1, D206.3
unnamed: D206.1, D207.3
unnamed: D207.1, D208.3
unnamed: D208.1, D209.3
unnamed: D209.1, D210.3
unnamed: D210.1, D211.3
unnamed: D211.1, D212.3
unnamed: D212.1, D213.3
unnamed: D213.1, D214.3
unnamed: D214.1, D215.3
unnamed: D215.1, D216.3
unnamed: D216.1, D217.3
unnamed: D217.1, D218.3
unnamed: D218.1, D219.3
unnamed: D219.1, D220.3
unnamed: D220.1, D221.3
unnamed: D221.1, D222.3
unnamed: D222.1, D223.3
unnamed: D223.1, D224.3
unnamed: D224.1, D225.3
unnamed: D225.1, D226.3
unnamed: D226.1, D227.3
unnamed: D227.1, D228.3
unnamed: D228.1, D229.3
unnamed: D229.1, D230.3
unnamed: D230.1, D231.3
unnamed: D231.1, D232.3
unnamed: D232.1, D233.3
unnamed: D233.1, D234.3
unnamed: D234.1, D235.3
unnamed: D235.1, D236.3
unnamed: D236.1, D237.3
unnamed: D237.1, D238.3
unnamed: D238.1, D239.3
unnamed: D239.1, D240.3
unnamed: D240.1, D241.3
unnamed: D241.1, D242.3
unnamed: D242.1, D243.3
unnamed: D243.1, D244.3
unnamed: D244.1, D245.3
unnamed: D245.1, D246.3
unnamed: D246.1, D247.3
unnamed: D247.1, D248.3
unnamed: D248.1, D249.3
unnamed: D249.1, D250.3
unnamed: D250.1, D251.3
unnamed: D251.1, D252.3
unnamed: D252.1, D253.3
unnamed: D253.1, D254.3
unnamed: D254.1, D255.3
unnamed: D255.1, D256.3
unnamed: D256.1, D257.3
unnamed: D257.1, D258.3
unnamed: D258.1, D259.3
unnamed: D259.1, D260.3
unnamed: D260.1, D261.3
unnamed: D261.1, D262.3
unnamed: D262.1, D263.3
unnamed: D263.1, D264.3
unnamed: D264.1, D265.3
unnamed: D265.1, D266.3
unnamed: D266.1, D267.3
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

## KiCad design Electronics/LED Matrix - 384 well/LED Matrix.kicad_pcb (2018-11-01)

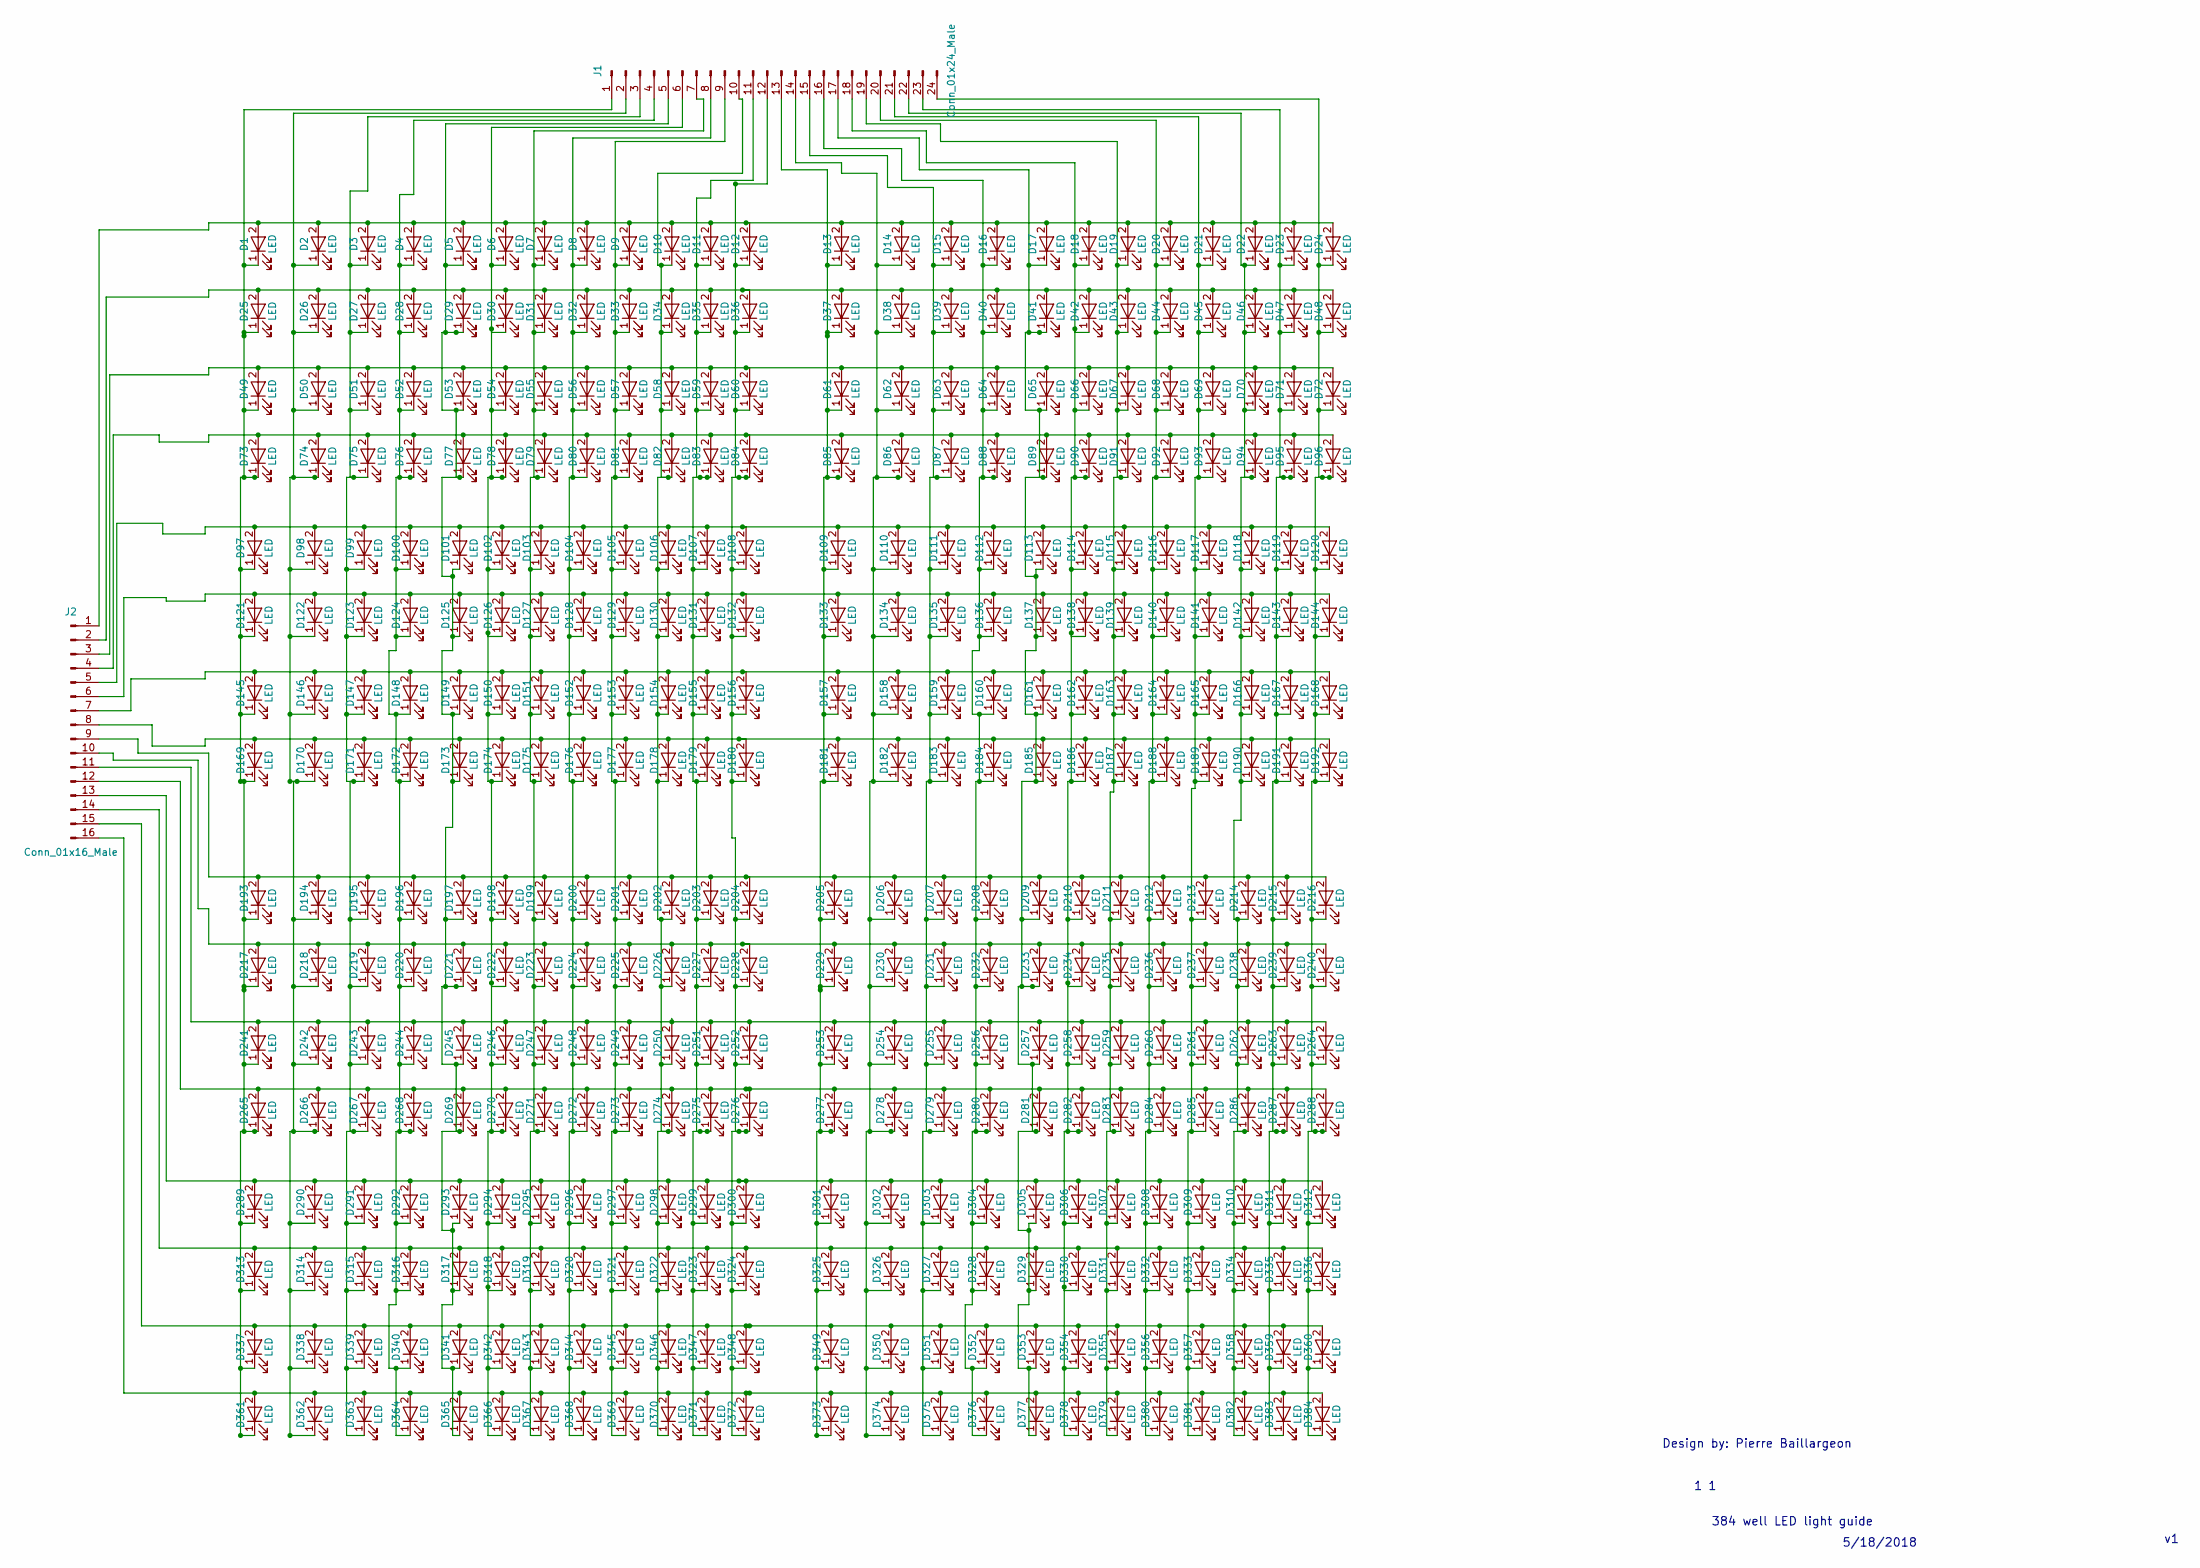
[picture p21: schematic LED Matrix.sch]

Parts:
D1, D2, D3, D4, D5, D6, D7, D8, D9, D10, D11, D12, D13, D14, D15, D16, D17, D18, D19, D20, D21, D22, D23, D24, D25, D26, D27, D28, D29, D30, D31, D32, D33, D34, D35, D36, D37, D38, D39, D40, D41, D42, D43, D44, D45, D46, D47, D48, D49, D50, D51, D52, D53, D54, D55, D56, D57, D58, D59, D60, D61, D62, D63, D64, D65, D66, D67, D68, D69, D70, D71, D72, D73, D74, D75, D76, D77, D78, D79, D80, D81, D82, D83, D84, D85, D86, D87, D88, D89, D90, D91, D92, D93, D94, D95, D96, D97, D98, D99, D100, D101, D102, D103, D104, D105, D106, D107, D108, D109, D110, D111, D112, D113, D114, D115, D116, D117, D118, D119, D120, D121, D122, D123, D124, D125, D126, D127, D128, D129, D130, D131, D132, D133, D134, D135, D136, D137, D138, D139, D140, D141, D142, D143, D144, D145, D146, D147, D148, D149, D150, D151, D152, D153, D154, D155, D156, D157, D158, D159, D160, D161, D162, D163, D164, D165, D166, D167, D168, D169, D170, D171, D172, D173, D174, D175, D176, D177, D178, D179, D180, D181, D182, D183, D184, D185, D186, D187, D188, D189, D190, D191, D192, D193, D194, D195, D196, D197, D198, D199, D200, D201, D202, D203, D204, D205, D206, D207, D208, D209, D210, D211, D212, D213, D214, D215, D216, D217, D218, D219, D220, D221, D222, D223, D224, D225, D226, D227, D228, D229, D230, D231, D232, D233, D234, D235, D236, D237, D238, D239, D240, D241, D242, D243, D244, D245, D246, D247, D248, D249, D250, D251, D252, D253, D254, D255, D256, D257, D258, D259, D260, D261, D262, D263, D264, D265, D266, D267, D268, D269, D270, D271, D272, D273, D274, D275, D276, D277, D278, D279, D280, D281, D282, D283, D284, D285, D286, D287, D288, D289, D290, D291, D292, D293, D294, D295, D296, D297, D298, D299, D300, D301, D302, D303, D304, D305, D306, D307, D308, D309, D310, D311, D312, D313, D314, D315, D316, D317, D318, D319, D320, D321, D322, D323, D324, D325, D326, D327, D328, D329, D330, D331, D332, D333, D334, D335, D336, D337, D338, D339, D340, D341, D342, D343, D344, D345, D346, D347, D348, D349, D350, D351, D352, D353, D354, D355, D356, D357, D358, D359, D360, D361, D362, D363, D364, D365, D366, D367, D368, D369, D370, D371, D372, D373, D374, D375, D376, D377, D378, D379, D380, D381, D382, D383, D384: LED; smallpadLED_D3.0mm
J1: Conn_01x24_Male; Pin_Header_Straight_1x24_Pitch2.54mm
J2: Conn_01x16_Male; Pin_Header_Straight_1x16_Pitch2.54mm

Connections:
unnamed: D1.1 (K), D25.1 (K), D49.1 (K), D73.1 (K), D97.1 (K), D121.1 (K), D145.1 (K), D169.1 (K), D193.1 (K), D217.1 (K), D241.1 (K), D265.1 (K), D289.1 (K), D313.1 (K), D337.1 (K), D361.1 (K), J1.1
unnamed: D1.2 (A), D2.2 (A), D3.2 (A), D4.2 (A), D5.2 (A), D6.2 (A), D7.2 (A), D8.2 (A), D9.2 (A), D10.2 (A), D11.2 (A), D12.2 (A), D13.2 (A), D14.2 (A), D15.2 (A), D16.2 (A), D17.2 (A), D18.2 (A), D19.2 (A), D20.2 (A), D21.2 (A), D22.2 (A), D23.2 (A), D24.2 (A), J2.1
unnamed: D10.1 (K), D34.1 (K), D58.1 (K), D82.1 (K), D106.1 (K), D130.1 (K), D154.1 (K), D178.1 (K), D202.1 (K), D226.1 (K), D250.1 (K), D274.1 (K), D298.1 (K), D322.1 (K), D346.1 (K), D370.1 (K), J1.10
unnamed: D25.2 (A), D26.2 (A), D27.2 (A), D28.2 (A), D29.2 (A), D30.2 (A), D31.2 (A), D32.2 (A), D33.2 (A), D34.2 (A), D35.2 (A), D36.2 (A), D37.2 (A), D38.2 (A), D39.2 (A), D40.2 (A), D41.2 (A), D42.2 (A), D43.2 (A), D44.2 (A), D45.2 (A), D46.2 (A), D47.2 (A), D48.2 (A), J2.2
unnamed: D49.2 (A), D50.2 (A), D51.2 (A), D52.2 (A), D53.2 (A), D54.2 (A), D55.2 (A), D56.2 (A), D57.2 (A), D58.2 (A), D59.2 (A), D60.2 (A), D61.2 (A), D62.2 (A), D63.2 (A), D64.2 (A), D65.2 (A), D66.2 (A), D67.2 (A), D68.2 (A), D69.2 (A), D70.2 (A), D71.2 (A), D72.2 (A), J2.3
unnamed: D73.2 (A), D74.2 (A), D75.2 (A), D76.2 (A), D77.2 (A), D78.2 (A), D79.2 (A), D80.2 (A), D81.2 (A), D82.2 (A), D83.2 (A), D84.2 (A), D85.2 (A), D86.2 (A), D87.2 (A), D88.2 (A), D89.2 (A), D90.2 (A), D91.2 (A), D92.2 (A), D93.2 (A), D94.2 (A), D95.2 (A), D96.2 (A), J2.4
unnamed: D4.1 (K), D28.1 (K), D52.1 (K), D76.1 (K), D100.1 (K), D124.1 (K), D148.1 (K), D172.1 (K), D196.1 (K), D220.1 (K), D244.1 (K), D268.1 (K), D292.1 (K), D316.1 (K), D340.1 (K), D364.1 (K), J1.4
unnamed: D97.2 (A), D98.2 (A), D99.2 (A), D100.2 (A), D101.2 (A), D102.2 (A), D103.2 (A), D104.2 (A), D105.2 (A), D106.2 (A), D107.2 (A), D108.2 (A), D109.2 (A), D110.2 (A), D111.2 (A), D112.2 (A), D113.2 (A), D114.2 (A), D115.2 (A), D116.2 (A), D117.2 (A), D118.2 (A), D119.2 (A), D120.2 (A), J2.5
unnamed: D5.1 (K), D29.1 (K), D53.1 (K), D77.1 (K), D101.1 (K), D125.1 (K), D149.1 (K), D173.1 (K), D197.1 (K), D221.1 (K), D245.1 (K), D269.1 (K), D293.1 (K), D317.1 (K), D341.1 (K), D365.1 (K), J1.5
unnamed: D6.1 (K), D30.1 (K), D54.1 (K), D78.1 (K), D102.1 (K), D126.1 (K), D150.1 (K), D174.1 (K), D198.1 (K), D222.1 (K), D246.1 (K), D270.1 (K), D294.1 (K), D318.1 (K), D342.1 (K), D366.1 (K), J1.6
unnamed: D7.1 (K), D31.1 (K), D55.1 (K), D79.1 (K), D103.1 (K), D127.1 (K), D151.1 (K), D175.1 (K), D199.1 (K), D223.1 (K), D247.1 (K), D271.1 (K), D295.1 (K), D319.1 (K), D343.1 (K), D367.1 (K), J1.7
unnamed: D8.1 (K), D32.1 (K), D56.1 (K), D80.1 (K), D104.1 (K), D128.1 (K), D152.1 (K), D176.1 (K), D200.1 (K), D224.1 (K), D248.1 (K), D272.1 (K), D296.1 (K), D320.1 (K), D344.1 (K), D368.1 (K), J1.8
unnamed: D9.1 (K), D33.1 (K), D57.1 (K), D81.1 (K), D105.1 (K), D129.1 (K), D153.1 (K), D177.1 (K), D201.1 (K), D225.1 (K), D249.1 (K), D273.1 (K), D297.1 (K), D321.1 (K), D345.1 (K), D369.1 (K), J1.9
unnamed: D11.1 (K), D35.1 (K), D59.1 (K), D83.1 (K), D107.1 (K), D131.1 (K), D155.1 (K), D179.1 (K), D203.1 (K), D227.1 (K), D251.1 (K), D275.1 (K), D299.1 (K), D323.1 (K), D347.1 (K), D371.1 (K), J1.11
unnamed: D12.1 (K), D36.1 (K), D60.1 (K), D84.1 (K), D108.1 (K), D132.1 (K), D156.1 (K), D180.1 (K), D204.1 (K), D228.1 (K), D252.1 (K), D276.1 (K), D300.1 (K), D324.1 (K), D348.1 (K), D372.1 (K), J1.12
unnamed: D13.1 (K), D37.1 (K), D61.1 (K), D85.1 (K), D109.1 (K), D133.1 (K), D157.1 (K), D181.1 (K), D205.1 (K), D229.1 (K), D253.1 (K), D277.1 (K), D301.1 (K), D325.1 (K), D349.1 (K), D373.1 (K), J1.13
unnamed: D14.1 (K), D38.1 (K), D62.1 (K), D86.1 (K), D110.1 (K), D134.1 (K), D158.1 (K), D182.1 (K), D206.1 (K), D230.1 (K), D254.1 (K), D278.1 (K), D302.1 (K), D326.1 (K), D350.1 (K), D374.1 (K), J1.14
unnamed: D15.1 (K), D39.1 (K), D63.1 (K), D87.1 (K), D111.1 (K), D135.1 (K), D159.1 (K), D183.1 (K), D207.1 (K), D231.1 (K), D255.1 (K), D279.1 (K), D303.1 (K), D327.1 (K), D351.1 (K), D375.1 (K), J1.15
unnamed: D16.1 (K), D40.1 (K), D64.1 (K), D88.1 (K), D112.1 (K), D136.1 (K), D160.1 (K), D184.1 (K), D208.1 (K), D232.1 (K), D256.1 (K), D280.1 (K), D304.1 (K), D328.1 (K), D352.1 (K), D376.1 (K), J1.16
unnamed: D17.1 (K), D41.1 (K), D65.1 (K), D89.1 (K), D113.1 (K), D137.1 (K), D161.1 (K), D185.1 (K), D209.1 (K), D233.1 (K), D257.1 (K), D281.1 (K), D305.1 (K), D329.1 (K), D353.1 (K), D377.1 (K), J1.17
unnamed: D18.1 (K), D42.1 (K), D66.1 (K), D90.1 (K), D114.1 (K), D138.1 (K), D162.1 (K), D186.1 (K), D210.1 (K), D234.1 (K), D258.1 (K), D282.1 (K), D306.1 (K), D330.1 (K), D354.1 (K), D378.1 (K), J1.18
unnamed: D19.1 (K), D43.1 (K), D67.1 (K), D91.1 (K), D115.1 (K), D139.1 (K), D163.1 (K), D187.1 (K), D211.1 (K), D235.1 (K), D259.1 (K), D283.1 (K), D307.1 (K), D331.1 (K), D355.1 (K), D379.1 (K), J1.19
unnamed: D20.1 (K), D44.1 (K), D68.1 (K), D92.1 (K), D116.1 (K), D140.1 (K), D164.1 (K), D188.1 (K), D212.1 (K), D236.1 (K), D260.1 (K), D284.1 (K), D308.1 (K), D332.1 (K), D356.1 (K), D380.1 (K), J1.20
unnamed: D21.1 (K), D45.1 (K), D69.1 (K), D93.1 (K), D117.1 (K), D141.1 (K), D165.1 (K), D189.1 (K), D213.1 (K), D237.1 (K), D261.1 (K), D285.1 (K), D309.1 (K), D333.1 (K), D357.1 (K), D381.1 (K), J1.21
unnamed: D22.1 (K), D46.1 (K), D70.1 (K), D94.1 (K), D118.1 (K), D142.1 (K), D166.1 (K), D190.1 (K), D214.1 (K), D238.1 (K), D262.1 (K), D286.1 (K), D310.1 (K), D334.1 (K), D358.1 (K), D382.1 (K), J1.22
unnamed: D23.1 (K), D47.1 (K), D71.1 (K), D95.1 (K), D119.1 (K), D143.1 (K), D167.1 (K), D191.1 (K), D215.1 (K), D239.1 (K), D263.1 (K), D287.1 (K), D311.1 (K), D335.1 (K), D359.1 (K), D383.1 (K), J1.23
unnamed: D24.1 (K), D48.1 (K), D72.1 (K), D96.1 (K), D120.1 (K), D144.1 (K), D168.1 (K), D192.1 (K), D216.1 (K), D240.1 (K), D264.1 (K), D288.1 (K), D312.1 (K), D336.1 (K), D360.1 (K), D384.1 (K), J1.24
unnamed: D121.2 (A), D122.2 (A), D123.2 (A), D124.2 (A), D125.2 (A), D126.2 (A), D127.2 (A), D128.2 (A), D129.2 (A), D130.2 (A), D131.2 (A), D132.2 (A), D133.2 (A), D134.2 (A), D135.2 (A), D136.2 (A), D137.2 (A), D138.2 (A), D139.2 (A), D140.2 (A), D141.2 (A), D142.2 (A), D143.2 (A), D144.2 (A), J2.6
unnamed: D2.1 (K), D26.1 (K), D50.1 (K), D74.1 (K), D98.1 (K), D122.1 (K), D146.1 (K), D170.1 (K), D194.1 (K), D218.1 (K), D242.1 (K), D266.1 (K), D290.1 (K), D314.1 (K), D338.1 (K), D362.1 (K), J1.2
unnamed: D3.1 (K), D27.1 (K), D51.1 (K), D75.1 (K), D99.1 (K), D123.1 (K), D147.1 (K), D171.1 (K), D195.1 (K), D219.1 (K), D243.1 (K), D267.1 (K), D291.1 (K), D315.1 (K), D339.1 (K), D363.1 (K), J1.3
unnamed: D145.2 (A), D146.2 (A), D147.2 (A), D148.2 (A), D149.2 (A), D150.2 (A), D151.2 (A), D152.2 (A), D153.2 (A), D154.2 (A), D155.2 (A), D156.2 (A), D157.2 (A), D158.2 (A), D159.2 (A), D160.2 (A), D161.2 (A), D162.2 (A), D163.2 (A), D164.2 (A), D165.2 (A), D166.2 (A), D167.2 (A), D168.2 (A), J2.7
unnamed: D169.2 (A), D170.2 (A), D171.2 (A), D172.2 (A), D173.2 (A), D174.2 (A), D175.2 (A), D176.2 (A), D177.2 (A), D178.2 (A), D179.2 (A), D180.2 (A), D181.2 (A), D182.2 (A), D183.2 (A), D184.2 (A), D185.2 (A), D186.2 (A), D187.2 (A), D188.2 (A), D189.2 (A), D190.2 (A), D191.2 (A), D192.2 (A), J2.8
unnamed: D193.2 (A), D194.2 (A), D195.2 (A), D196.2 (A), D197.2 (A), D198.2 (A), D199.2 (A), D200.2 (A), D201.2 (A), D202.2 (A), D203.2 (A), D204.2 (A), D205.2 (A), D206.2 (A), D207.2 (A), D208.2 (A), D209.2 (A), D210.2 (A), D211.2 (A), D212.2 (A), D213.2 (A), D214.2 (A), D215.2 (A), D216.2 (A), J2.9
unnamed: D217.2 (A), D218.2 (A), D219.2 (A), D220.2 (A), D221.2 (A), D222.2 (A), D223.2 (A), D224.2 (A), D225.2 (A), D226.2 (A), D227.2 (A), D228.2 (A), D229.2 (A), D230.2 (A), D231.2 (A), D232.2 (A), D233.2 (A), D234.2 (A), D235.2 (A), D236.2 (A), D237.2 (A), D238.2 (A), D239.2 (A), D240.2 (A), J2.10
unnamed: D241.2 (A), D242.2 (A), D243.2 (A), D244.2 (A), D245.2 (A), D246.2 (A), D247.2 (A), D248.2 (A), D249.2 (A), D250.2 (A), D251.2 (A), D252.2 (A), D253.2 (A), D254.2 (A), D255.2 (A), D256.2 (A), D257.2 (A), D258.2 (A), D259.2 (A), D260.2 (A), D261.2 (A), D262.2 (A), D263.2 (A), D264.2 (A), J2.11
unnamed: D265.2 (A), D266.2 (A), D267.2 (A), D268.2 (A), D269.2 (A), D270.2 (A), D271.2 (A), D272.2 (A), D273.2 (A), D274.2 (A), D275.2 (A), D276.2 (A), D277.2 (A), D278.2 (A), D279.2 (A), D280.2 (A), D281.2 (A), D282.2 (A), D283.2 (A), D284.2 (A), D285.2 (A), D286.2 (A), D287.2 (A), D288.2 (A), J2.12
unnamed: D289.2 (A), D290.2 (A), D291.2 (A), D292.2 (A), D293.2 (A), D294.2 (A), D295.2 (A), D296.2 (A), D297.2 (A), D298.2 (A), D299.2 (A), D300.2 (A), D301.2 (A), D302.2 (A), D303.2 (A), D304.2 (A), D305.2 (A), D306.2 (A), D307.2 (A), D308.2 (A), D309.2 (A), D310.2 (A), D311.2 (A), D312.2 (A), J2.13
unnamed: D313.2 (A), D314.2 (A), D315.2 (A), D316.2 (A), D317.2 (A), D318.2 (A), D319.2 (A), D320.2 (A), D321.2 (A), D322.2 (A), D323.2 (A), D324.2 (A), D325.2 (A), D326.2 (A), D327.2 (A), D328.2 (A), D329.2 (A), D330.2 (A), D331.2 (A), D332.2 (A), D333.2 (A), D334.2 (A), D335.2 (A), D336.2 (A), J2.14
unnamed: D337.2 (A), D338.2 (A), D339.2 (A), D340.2 (A), D341.2 (A), D342.2 (A), D343.2 (A), D344.2 (A), D345.2 (A), D346.2 (A), D347.2 (A), D348.2 (A), D349.2 (A), D350.2 (A), D351.2 (A), D352.2 (A), D353.2 (A), D354.2 (A), D355.2 (A), D356.2 (A), D357.2 (A), D358.2 (A), D359.2 (A), D360.2 (A), J2.15
unnamed: D361.2 (A), D362.2 (A), D363.2 (A), D364.2 (A), D365.2 (A), D366.2 (A), D367.2 (A), D368.2 (A), D369.2 (A), D370.2 (A), D371.2 (A), D372.2 (A), D373.2 (A), D374.2 (A), D375.2 (A), D376.2 (A), D377.2 (A), D378.2 (A), D379.2 (A), D380.2 (A), D381.2 (A), D382.2 (A), D383.2 (A), D384.2 (A), J2.16

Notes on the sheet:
384 well LED light guide
5/18/2018
Design by: Pierre Baillargeon

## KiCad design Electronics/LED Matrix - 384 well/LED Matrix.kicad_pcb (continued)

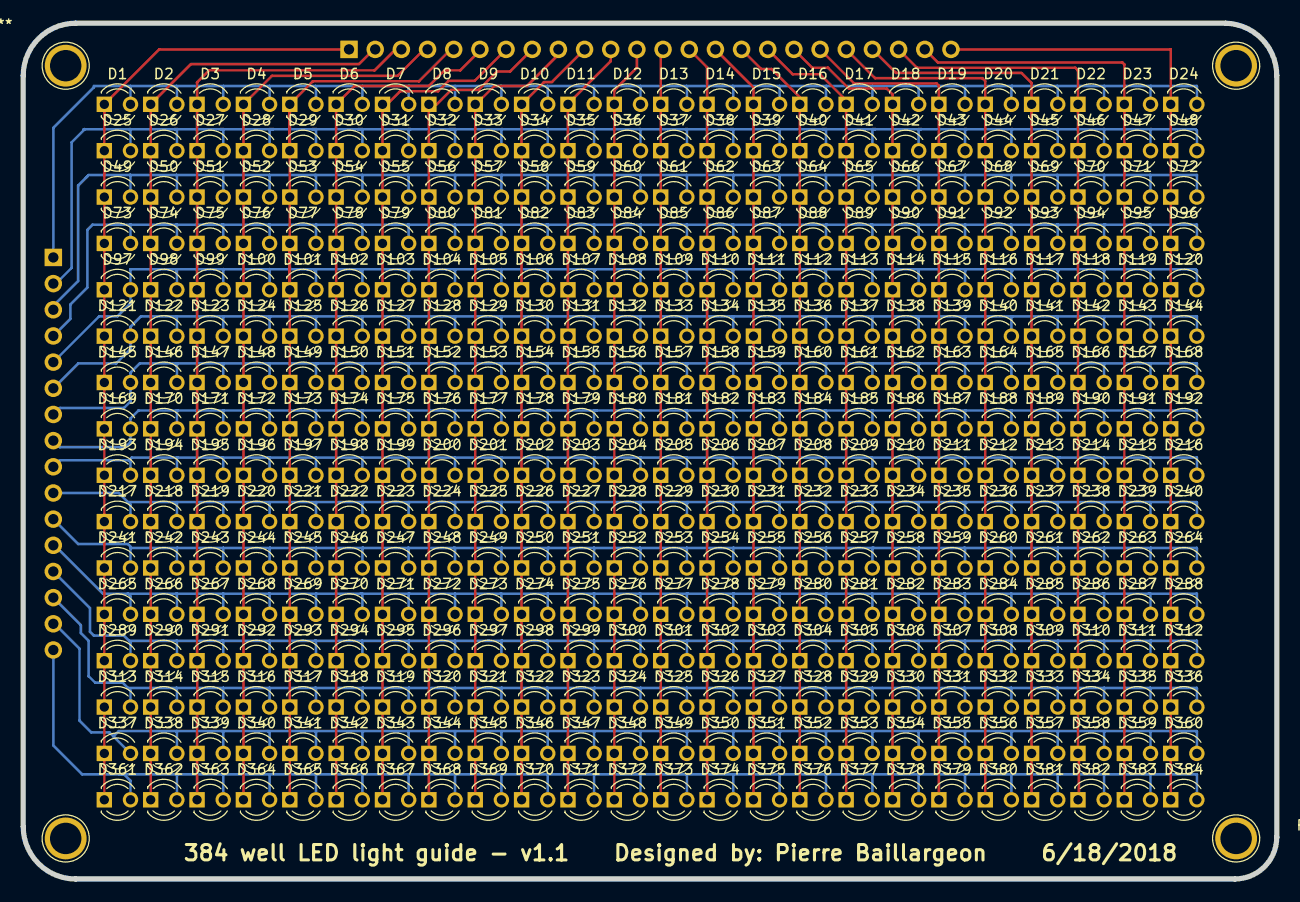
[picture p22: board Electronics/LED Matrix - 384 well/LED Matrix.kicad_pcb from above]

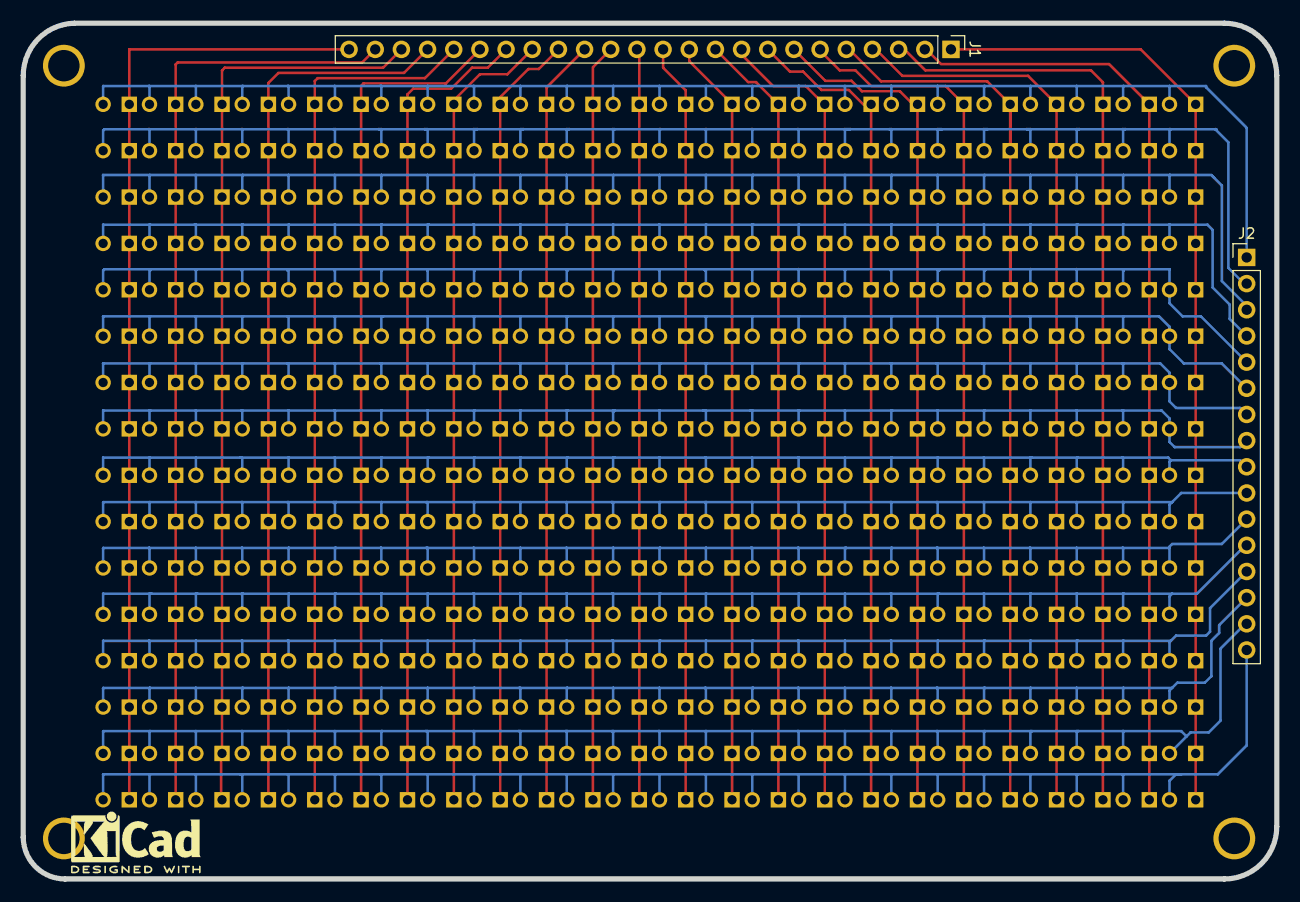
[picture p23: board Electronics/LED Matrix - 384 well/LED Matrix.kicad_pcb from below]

Board: 2 copper layers, 121.7 x 83.1 mm, 386 parts (2 on the bottom side), 40 nets.

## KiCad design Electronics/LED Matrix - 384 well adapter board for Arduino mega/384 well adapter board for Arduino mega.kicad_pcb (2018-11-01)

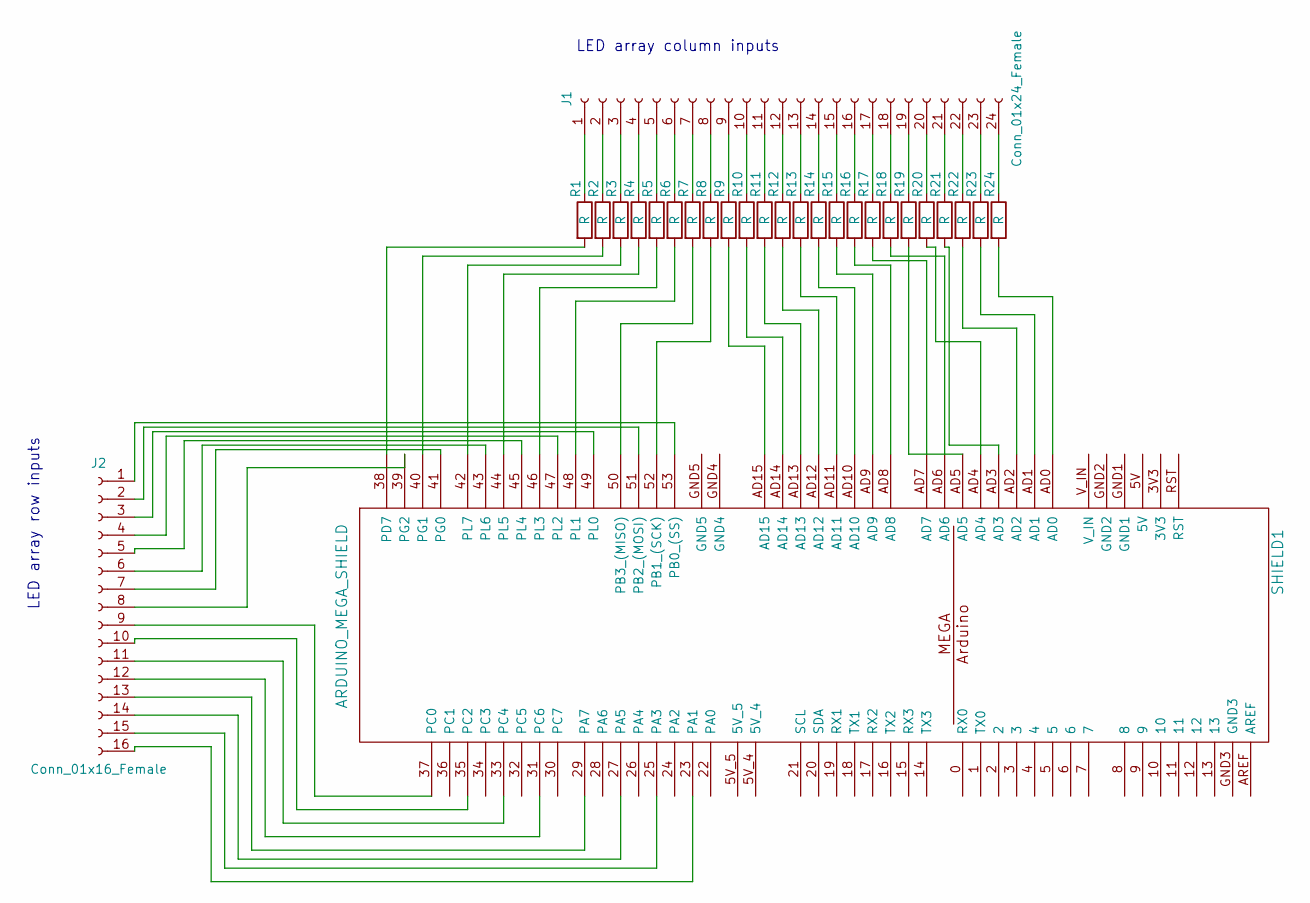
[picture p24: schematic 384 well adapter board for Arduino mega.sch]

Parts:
J1: Conn_01x24_Female; Socket_Strip_Straight_1x24_Pitch2.54mm
J2: Conn_01x16_Female; Socket_Strip_Straight_1x16_Pitch2.54mm
R1, R2, R3, R4, R5, R6, R7, R8, R9, R10, R11, R12, R13, R14, R15, R16, R17, R18, R19, R20, R21, R22, R23, R24: R; R_Axial_DIN0207_L6.3mm_D2.5mm_P7.62mm_Horizontal
SHIELD1: ARDUINO_MEGA_SHIELD; ARDUINO MEGA SHIELD

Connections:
unnamed: J1.1, R1.1
unnamed: J1.2, R2.1
unnamed: J1.3, R3.1
unnamed: J1.4, R4.1
unnamed: J1.5, R5.1
unnamed: J1.6, R6.1
unnamed: J1.7, R7.1
unnamed: J1.8, R8.1
unnamed: J1.9, R9.1
unnamed: J1.10, R10.1
unnamed: J1.11, R11.1
unnamed: J1.12, R12.1
unnamed: J1.13, R13.1
unnamed: J1.14, R14.1
unnamed: J1.15, R15.1
unnamed: J1.16, R16.1
unnamed: J1.17, R17.1
unnamed: J1.18, R18.1
unnamed: J1.19, R19.1
unnamed: J1.20, R20.1
unnamed: J1.21, R21.1
unnamed: J1.22, R22.1
unnamed: J1.23, R23.1
unnamed: J1.24, R24.1
unnamed: J2.1, SHIELD1.53 (PB0_(SS))
unnamed: J2.2, SHIELD1.51 (PB2_(MOSI))
unnamed: J2.3, SHIELD1.49 (PL0)
unnamed: J2.4, SHIELD1.47 (PL2)
unnamed: J2.5, SHIELD1.45 (PL4)
unnamed: J2.6, SHIELD1.43 (PL6)
unnamed: J2.7, SHIELD1.41 (PG0)
unnamed: J2.8, SHIELD1.39 (PG2)
unnamed: J2.9, SHIELD1.37 (PC0)
unnamed: J2.10, SHIELD1.35 (PC2)
unnamed: J2.11, SHIELD1.33 (PC4)
unnamed: J2.12, SHIELD1.31 (PC6)
unnamed: J2.13, SHIELD1.29 (PA7)
unnamed: J2.14, SHIELD1.27 (PA5)
unnamed: J2.15, SHIELD1.25 (PA3)
unnamed: J2.16, SHIELD1.23 (PA1)
unnamed: R1.2, SHIELD1.38 (PD7)
unnamed: R2.2, SHIELD1.40 (PG1)
unnamed: R3.2, SHIELD1.42 (PL7)
unnamed: R4.2, SHIELD1.44 (PL5)
unnamed: R5.2, SHIELD1.46 (PL3)
unnamed: R6.2, SHIELD1.48 (PL1)
unnamed: R7.2, SHIELD1.50 (PB3_(MISO))
unnamed: R8.2, SHIELD1.52 (PB1_(SCK))
unnamed: R9.2, SHIELD1.AD15
unnamed: R10.2, SHIELD1.AD14
unnamed: R11.2, SHIELD1.AD13
unnamed: R12.2, SHIELD1.AD12
unnamed: R13.2, SHIELD1.AD11
unnamed: R14.2, SHIELD1.AD10
unnamed: R15.2, SHIELD1.AD9
unnamed: R16.2, SHIELD1.AD8
unnamed: R17.2, SHIELD1.AD7
unnamed: R18.2, SHIELD1.AD6
unnamed: R19.2, SHIELD1.AD5
unnamed: R20.2, SHIELD1.AD4
unnamed: R21.2, SHIELD1.AD3
unnamed: R22.2, SHIELD1.AD2
unnamed: R23.2, SHIELD1.AD1
unnamed: R24.2, SHIELD1.AD0

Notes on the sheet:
LED array column inputs
LED array row inputs

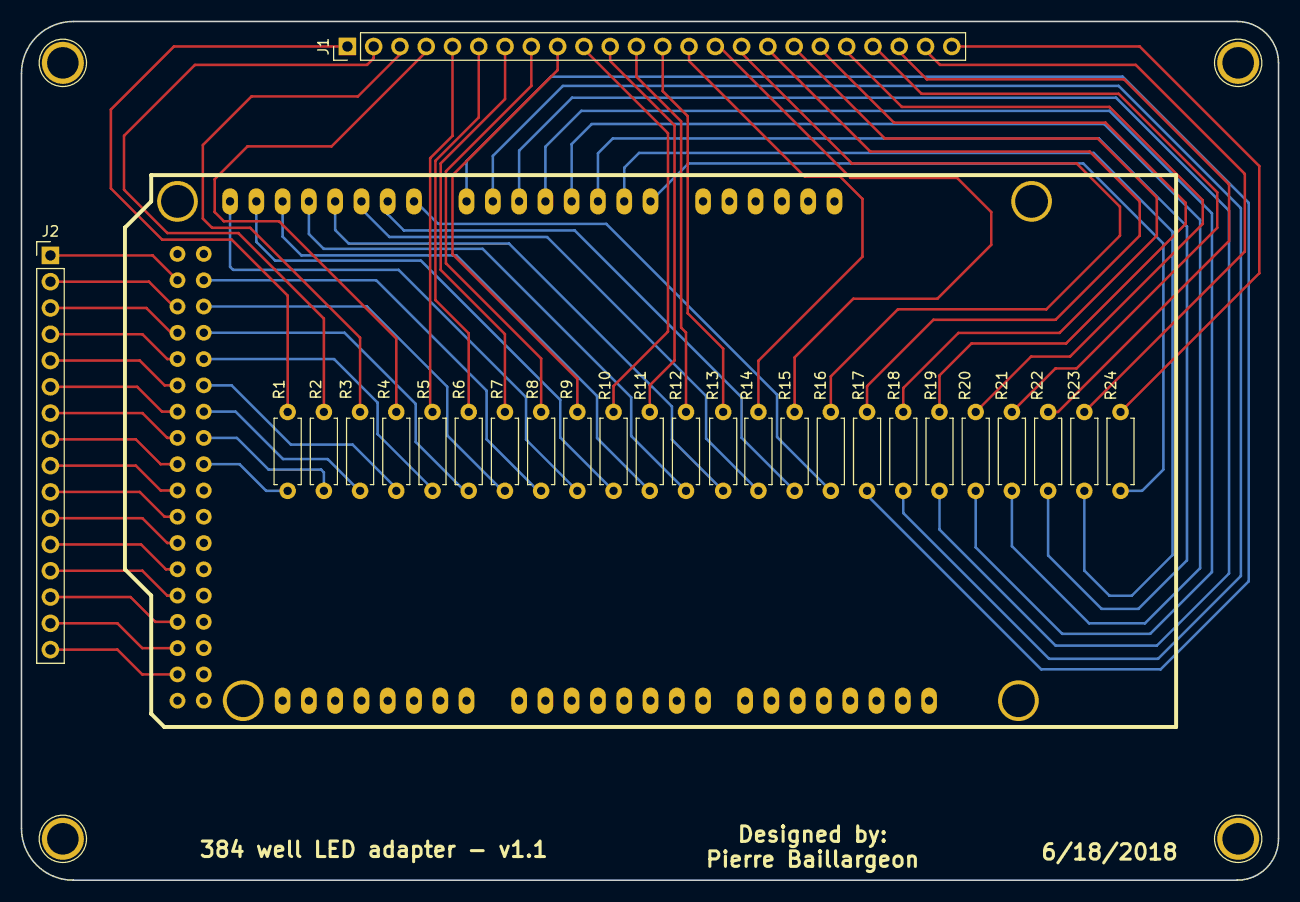
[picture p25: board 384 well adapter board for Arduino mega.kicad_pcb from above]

Board: 2 copper layers, 121.5 x 83.0 mm, 27 parts (0 on the bottom side), 64 nets.

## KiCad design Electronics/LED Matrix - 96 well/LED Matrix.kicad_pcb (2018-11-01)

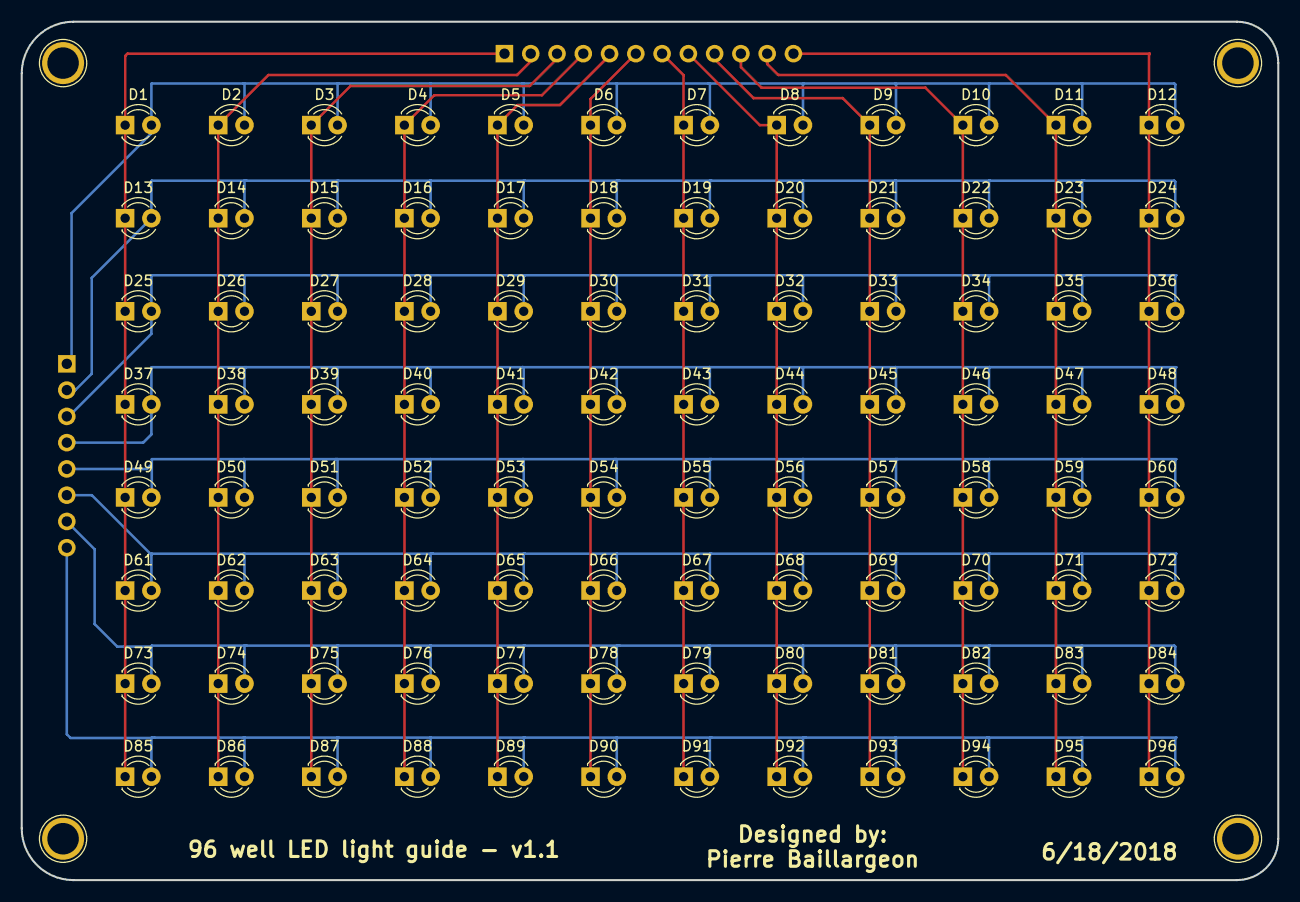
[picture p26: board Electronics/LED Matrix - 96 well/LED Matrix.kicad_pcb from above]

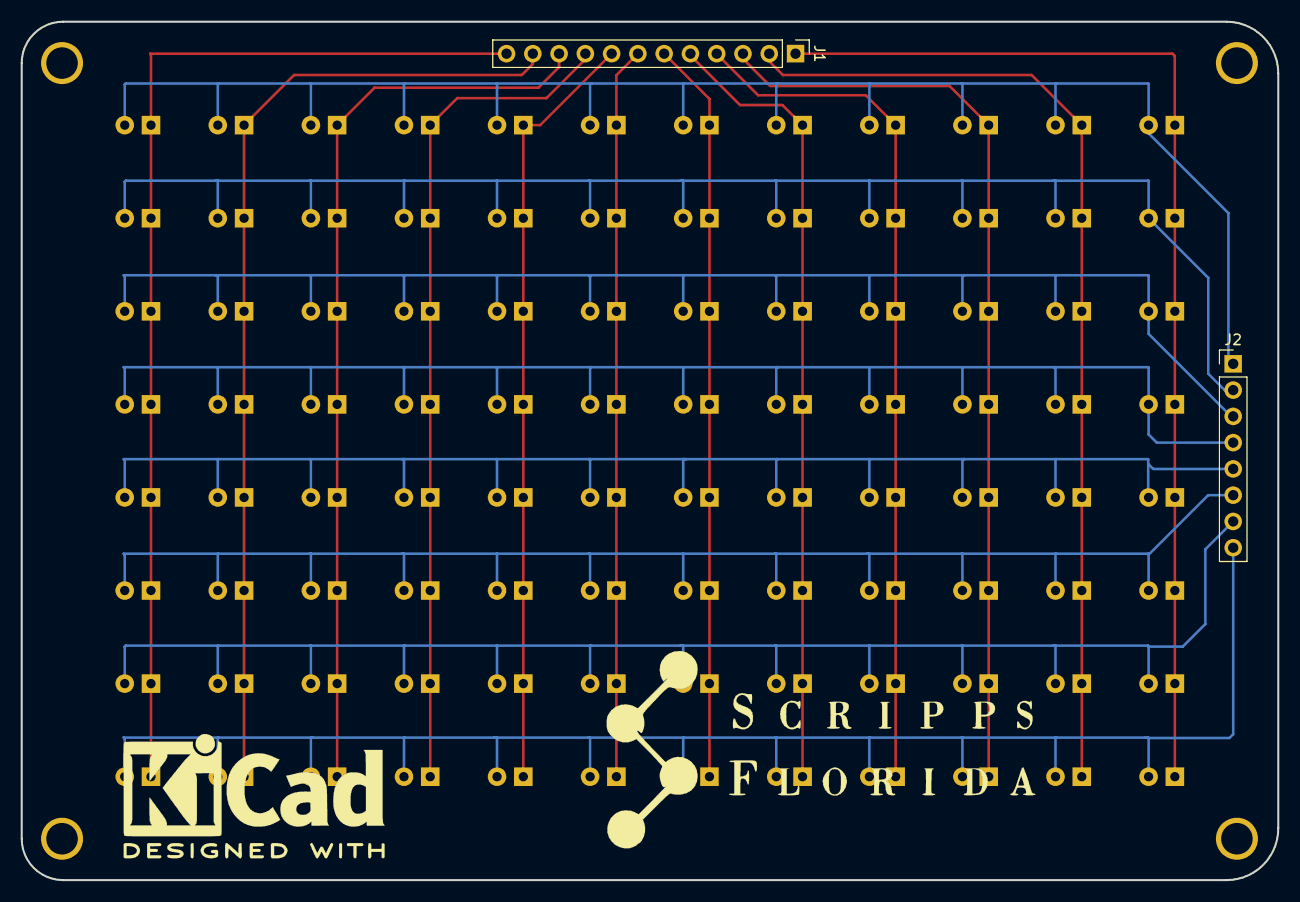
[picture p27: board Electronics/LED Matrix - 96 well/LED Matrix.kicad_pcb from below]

Board: 2 copper layers, 121.5 x 83.0 mm, 98 parts (2 on the bottom side), 20 nets.

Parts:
D1, D2, D3, D4, D5, D6, D7, D8, D9, D10, D11, D12, D13, D14, D15, D16, D17, D18, D19, D20, D21, D22, D23, D24, D25, D26, D27, D28, D29, D30, D31, D32, D33, D34, D35, D36, D37, D38, D39, D40, D41, D42, D43, D44, D45, D46, D47, D48, D49, D50, D51, D52, D53, D54, D55, D56, D57, D58, D59, D60, D61, D62, D63, D64, D65, D66, D67, D68, D69, D70, D71, D72, D73, D74, D75, D76, D77, D78, D79, D80, D81, D82, D83, D84, D85, D86, D87, D88, D89, D90, D91, D92, D93, D94, D95, D96: LED; LED_D3.0mm
J1: Conn_01x12_Male; Pin_Header_Straight_1x12_Pitch2.54mm
J2: Conn_01x08_Male; Pin_Header_Straight_1x08_Pitch2.54mm

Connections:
/1: D1.1, D13.1, D25.1, D37.1, D49.1, D61.1, D73.1, D85.1, J1.1
/2: D2.1, D14.1, D26.1, D38.1, D50.1, D62.1, D74.1, D86.1, J1.2
/3: D3.1, D15.1, D27.1, D39.1, D51.1, D63.1, D75.1, D87.1, J1.3
/4: D4.1, D16.1, D28.1, D40.1, D52.1, D64.1, D76.1, D88.1, J1.4
/5: D5.1, D17.1, D29.1, D41.1, D53.1, D65.1, D77.1, D89.1, J1.5
/6: D6.1, D18.1, D30.1, D42.1, D54.1, D66.1, D78.1, D90.1, J1.6
/7: D7.1, D19.1, D31.1, D43.1, D55.1, D67.1, D79.1, D91.1, J1.7
/8: D8.1, D20.1, D32.1, D44.1, D56.1, D68.1, D80.1, D92.1, J1.8
/9: D9.1, D21.1, D33.1, D45.1, D57.1, D69.1, D81.1, D93.1, J1.9
/10: D10.1, D22.1, D34.1, D46.1, D58.1, D70.1, D82.1, D94.1, J1.10
/11: D11.1, D23.1, D35.1, D47.1, D59.1, D71.1, D83.1, D95.1, J1.11
/12: D12.1, D24.1, D36.1, D48.1, D60.1, D72.1, D84.1, D96.1, J1.12
/A: D1.2, D2.2, D3.2, D4.2, D5.2, D6.2, D7.2, D8.2, D9.2, D10.2, D11.2, D12.2, J2.1
/B: D13.2, D14.2, D15.2, D16.2, D17.2, D18.2, D19.2, D20.2, D21.2, D22.2, D23.2, D24.2, J2.2
/C: D25.2, D26.2, D27.2, D28.2, D29.2, D30.2, D31.2, D32.2, D33.2, D34.2, D35.2, D36.2, J2.3
/D: D37.2, D38.2, D39.2, D40.2, D41.2, D42.2, D43.2, D44.2, D45.2, D46.2, D47.2, D48.2, J2.4
/E: D49.2, D50.2, D51.2, D52.2, D53.2, D54.2, D55.2, D56.2, D57.2, D58.2, D59.2, D60.2, J2.5
/F: D61.2, D62.2, D63.2, D64.2, D65.2, D66.2, D67.2, D68.2, D69.2, D70.2, D71.2, D72.2, J2.6
/G: D73.2, D74.2, D75.2, D76.2, D77.2, D78.2, D79.2, D80.2, D81.2, D82.2, D83.2, D84.2, J2.7
/H: D85.2, D86.2, D87.2, D88.2, D89.2, D90.2, D91.2, D92.2, D93.2, D94.2, D95.2, D96.2, J2.8

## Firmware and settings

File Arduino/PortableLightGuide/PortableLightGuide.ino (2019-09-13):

/* Arduino firmware for portable light guide     */
/* Scripps Florida                               */ 
/* Author: Pierre Baillargeon                    */
/* Correspondence: bpierre@scripps.edu           */ 
/* Date: 7/1/2019                                */ 

#include <Adafruit_NeoPixel.h>
/* This code requires the Button Arduino library v1.0.0 by Michael Adams */ 
#include <Button.h>
#ifdef __AVR__
  #include <avr/power.h>
#endif

/* The PIN variable should be set to the I/O pin that your microcontroller is using to send data to your light panel */ 
#define PIN 4
/* NUM_LEDS should be set to 96 or 384 */ 
#define NUM_LEDS 384
/* NUM_COLUMNS should be set to 12 or 24 */ 
/* #define NUM_COLUMNS 24 */ 
/* Valid brightness values are between 0 and 255 - do NOT set brightness above 100 unless your power supply can provide
 * adequate current for the given light panel.
 */
#define BRIGHTNESS 50

/* Set the I/O pin for your button to be used to indicate 'forward' in the program below */ 
Button forwardButton(3);
/* Set the I/O pin for your button to be used to change the main software mode below */ 
Button modeButton(2);

/* The operationMode variable is used to track which of the three main modes the device is currently in: 
 * Mode 2 is HTS demo mode, 0 is titration mode and 1 is illumination mode
 */
int operationMode=1;
/* The modeCounter variable is used to track the sub-state within each of the three main modes */ 
int modeCounter=0;

/* The randomValue, currentRow, rowEndValue, wellNumber, activePixelNumbeer, controlWell and hitIntensity variables
 * are used to in the HTS demo mode including the serpentine dispense pattern visualization.
 */
int randomValue=0; 
int currentRow=0;
int rowEndValue=0;
int wellNumber=0;
int activePixelNumber=0;
int controlWell=0;
int hitIntensity=0;
int NUM_COLUMNS=0;

Adafruit_NeoPixel strip = Adafruit_NeoPixel(NUM_LEDS, PIN, NEO_GRB + NEO_KHZ800);

void setup() {

  forwardButton.begin();
  modeButton.begin();

  if(NUM_LEDS==96) {
    NUM_COLUMNS=12;
  }
  else if(NUM_LEDS==384) {
    NUM_COLUMNS=24;
  }

  // This is for Trinket 5V 16MHz, you can remove these three lines if you are not using a Trinket
  #if defined (__AVR_ATtiny85__)
    if (F_CPU == 16000000) clock_prescale_set(clock_div_1);
  #endif
  // End of trinket special code
  strip.setBrightness(BRIGHTNESS);
  strip.begin();
  strip.show(); // Initialize all pixels to 'off'
    
}


void loop() {

  if(modeButton.pressed()) {
    processButtonPush(1);
  }
  if(forwardButton.pressed()){
    processButtonPush(0);
  }
  
}

/* Button ID 0 is next item, button ID 1 is next mode */ 
void processButtonPush(int buttonID) {
   
   /* Check to see which button was pressed and increment the related counter */ 
   if(buttonID==0) {
     modeCounter++;
   }
   if(buttonID==1){
     if(operationMode<2){
      operationMode++;
     }
     else{
      operationMode=0;
     }
     modeCounter=0;     
   }
      
   /* Call the function responsible for updating the delay based on the operationMode and modeCounter state chart */ 
   changeState(operationMode,modeCounter);
   
}
  
void changeState(int operationState, int stateCounter) {

  if(operationState==2) {
    /* Turn on a single red LED on pixel 0 to indicate that we are in illumination mode */ 
    if(stateCounter==0) {
      clearDisplay();
      strip.setPixelColor(0,strip.Color(255,0,0)); 
      strip.show();
    }
    if(stateCounter==1) {
      /* Simulating cell dispense with serpentine pattern */ 
      for(int j = 0; j < NUM_LEDS ; j++){
        wellNumber=j+1;
        currentRow = floor((wellNumber-1)/NUM_COLUMNS);
        rowEndValue = NUM_COLUMNS * (currentRow+1);
        if(currentRow == 0 or currentRow % 2 == 0) {
          activePixelNumber = j;
        }
        else {
          activePixelNumber = (rowEndValue-wellNumber-(NUM_COLUMNS-1)) + rowEndValue;
          activePixelNumber = activePixelNumber - 1;
        }
        strip.setPixelColor(activePixelNumber,strip.Color(180,0,0)); 
        delay(10);
        strip.show();
      }
    }
    
    /* Simulating read reagent dispense with serpentine pattern */ 
    if(stateCounter==2) {       
      for(int j = 0; j < NUM_LEDS ; j++){
        wellNumber=j+1;
        currentRow = floor((wellNumber-1)/NUM_COLUMNS);
        rowEndValue = NUM_COLUMNS * (currentRow+1);
        if(currentRow == 0 or currentRow % 2 == 0) {
          activePixelNumber = j;
        }
        else {
          activePixelNumber = (rowEndValue-wellNumber-(NUM_COLUMNS-1)) + rowEndValue;
          activePixelNumber = activePixelNumber - 1;
        }
        strip.setPixelColor(activePixelNumber,strip.Color(255,255,0)); 
        delay(10);
        strip.show();  
      }     
    } 
    
    /* Simulating plate reader excitation light */ 
    else if(stateCounter==3) {
      for(int j = 0; j < NUM_LEDS ; j++){
        strip.setPixelColor(j,strip.Color(0,0,255));        
      } 
      strip.show();   
    }  

    /* Simulating plate reader emission light */ 
    else if(stateCounter==4) {    
      for(int j = 0; j < NUM_LEDS ; j++){
        randomValue=random(6);      
        controlWell=0;  
        if(NUM_LEDS==96) {      
         if(j==0 || j==12 || j==24 || j==36 || j==48 || j==60 || j==72 || j==84 ) {
          controlWell=1;              
         }
         if(j==11 || j==23 || j==35 || j==47 || j==59 || j==71 || j==83 || j==95 ) { 
          randomValue=-1;
         }
        }
        else if(NUM_LEDS==384) {
          if(j==0 || j==24 || j==48 || j==36 || j==72 || j==96 || j==120 || j==144 || j==168 || j==192 || j==216 || j==240 || j==264 || j==288 || j==312 || j==336 || j==360 ) { 
            controlWell=1;                
          }
          if(j==23 || j==47 || j==71 || j==95 || j==119 || j==143 || j==167 || j==191 || j==215 || j==239 || j==263 || j==287 || j==311 || j==335 || j==359 || j==383 ) { 
            randomValue=-1;
          }      
        }                         
        
        if(randomValue==1 && controlWell==0){ 
          hitIntensity=random(255);
          strip.setPixelColor(j,strip.Color(0,hitIntensity,0)); 
        }
        else if(controlWell==1){
          strip.setPixelColor(j,strip.Color(0,255,0)); 
        }
        else if(randomValue==-1){
          strip.setPixelColor(j,strip.Color(0,0,25)); 
        }
        else{
          strip.setPixelColor(j,strip.Color(0,0,255)); 
        }
      } 
      strip.show();          
    }      
    
    /* Turn all LEDs off to reset the simulation */ 
    else if(stateCounter>4){
      clearDisplay();      
      strip.show();     
      modeCounter=0;
    }
  }
  
  /* Titration demo mode */ 
  else if(operationState==0) {
     for(int j = 0; j < NUM_LEDS ; j++){
        strip.setPixelColor(j,strip.Color(0,0,0));       
     }   
    /* Turn on a single orange LED on pixel 0 to indicate that we are in illumination mode */ 
    if(stateCounter==0) {
      clearDisplay();
      strip.setPixelColor(0,strip.Color(255,165,0)); 
      strip.show();    
    }      
    if(NUM_LEDS==96) {      
      strip.setPixelColor(stateCounter+1,strip.Color(255,165,0));
      strip.setPixelColor(stateCounter+13,strip.Color(255,165,0));
      strip.setPixelColor(stateCounter+25,strip.Color(255,165,0));
      strip.setPixelColor(stateCounter+37,strip.Color(255,165,0));
      strip.setPixelColor(stateCounter+49,strip.Color(255,165,0));
      strip.setPixelColor(stateCounter+61,strip.Color(255,165,0));
      strip.setPixelColor(stateCounter+73,strip.Color(255,165,0));
      strip.setPixelColor(stateCounter+85,strip.Color(255,165,0));      
      if(stateCounter==9) {
        modeCounter=0;
      }          
    }      
    else if(NUM_LEDS==384) {
      if(stateCounter!=0 && stateCounter<11) {
        for(int columnOnePixel=1; columnOnePixel<364; columnOnePixel+=24) {
          strip.setPixelColor(stateCounter+columnOnePixel,strip.Color(255,165,0));  
        }
        for(int columnTwoPixel=11; columnTwoPixel<374; columnTwoPixel+=24) {
          strip.setPixelColor(stateCounter+columnTwoPixel,strip.Color(255,165,0));  
        }       
      }     
      else if(stateCounter==11) {
        /* if we have shown the 10 titration operations, show the final brightness decrease to represent titration curves */
        for(int titrationCurveDisplay=0; titrationCurveDisplay< 384 ; titrationCurveDisplay+=24){
          setPixelColorBrightness(titrationCurveDisplay,0,0,0,100);
          setPixelColorBrightness(titrationCurveDisplay+1,0,0,0,100);
          setPixelColorBrightness(titrationCurveDisplay+2,255,165,0,100);
          setPixelColorBrightness(titrationCurveDisplay+3,255,165,0,80);
          setPixelColorBrightness(titrationCurveDisplay+4,255,165,0,65);
          setPixelColorBrightness(titrationCurveDisplay+5,255,165,0,55);
          setPixelColorBrightness(titrationCurveDisplay+6,255,165,0,45);
          setPixelColorBrightness(titrationCurveDisplay+7,255,165,0,35);
          setPixelColorBrightness(titrationCurveDisplay+8,255,165,0,25);
          setPixelColorBrightness(titrationCurveDisplay+9,255,165,0,20);     
          setPixelColorBrightness(titrationCurveDisplay+10,255,165,0,15);     
          setPixelColorBrightness(titrationCurveDisplay+11,255,165,0,0);     
          setPixelColorBrightness(titrationCurveDisplay+12,255,165,0,100);
          setPixelColorBrightness(titrationCurveDisplay+13,255,165,0,80);
          setPixelColorBrightness(titrationCurveDisplay+14,255,165,0,65);
          setPixelColorBrightness(titrationCurveDisplay+15,255,165,0,55);
          setPixelColorBrightness(titrationCurveDisplay+16,255,165,0,45);
          setPixelColorBrightness(titrationCurveDisplay+17,255,165,0,35);
          setPixelColorBrightness(titrationCurveDisplay+18,255,165,0,25);
          setPixelColorBrightness(titrationCurveDisplay+19,255,165,0,20);     
          setPixelColorBrightness(titrationCurveDisplay+20,255,165,0,15);     
          setPixelColorBrightness(titrationCurveDisplay+21,255,165,0,0);  
          setPixelColorBrightness(titrationCurveDisplay+22,0,0,0,100);
          setPixelColorBrightness(titrationCurveDisplay+23,0,0,0,100);              
        }      
      }          
      if(stateCounter==12) {
        modeCounter=0;
      }          
    }       
    
    strip.show();
  }
  
  /* Illumination mode */ 
  else if(operationState==1) {
    /* Turn on a single purple LED on pixel 0 to indicate that we are in illumination mode */  
    if(stateCounter==0){
      clearDisplay();
      strip.setPixelColor(0,strip.Color(75,0,130)); 
      strip.show();  
    }
    /* Illuminate all LEDs red */
    if(stateCounter==1) {
      for(int j = 0; j < NUM_LEDS ; j++){
        strip.setPixelColor(j,strip.Color(255,0,0));       
      } 
    }
    /* Illuminate all LEDs blue */ 
    else if(stateCounter==2) {
      for(int j = 0; j < NUM_LEDS ; j++){
        strip.setPixelColor(j,strip.Color(0,0,255));       
      } 
    }
    /* Illuminate all LEDs green */ 
    else if(stateCounter==3) {
      for(int j = 0; j < NUM_LEDS ; j++){
        strip.setPixelColor(j,strip.Color(0,255,0));       
      }   
    }
    /* Illuminate all LEDs orange */ 
    else if(stateCounter==4) {
      for(int j = 0; j < NUM_LEDS ; j++){
        strip.setPixelColor(j,strip.Color(255,165,0));       
      }     
    }
    /* Illuminate all LEDs white */ 
    else if(stateCounter==5) {
      for(int j = 0; j < NUM_LEDS ; j++){
        strip.setPixelColor(j,strip.Color(255,255,255));       
      }   
    }    
    /* Illuminate all LEDs violet */ 
    else if(stateCounter==6) {
      for(int j = 0; j < NUM_LEDS ; j++){
        strip.setPixelColor(j,strip.Color(160,32,240));       
      }   
    }    
    /* Illuminate all LEDs yellow */ 
    else if(stateCounter==7) {
      for(int j = 0; j < NUM_LEDS ; j++){
        strip.setPixelColor(j,strip.Color(255,255,0));       
      }    
    }    
    /* Illuminate all LEDs indigo */ 
    else if(stateCounter==8) {
      for(int j = 0; j < NUM_LEDS ; j++){
        strip.setPixelColor(j,strip.Color(75,0,130));       
      }              
      modeCounter=0;
    }
    strip.show();    
  }
  return;
}

void clearDisplay() {
  for(int x=0;x<NUM_LEDS;x++) {
    strip.setPixelColor(x,strip.Color(0,0,0));
  }
  return;
}



void setPixelColorBrightness( uint16_t n, uint8_t r, uint8_t g, uint8_t b, uint16_t brightness) {
   strip.setPixelColor(n, (brightness*r/255) , (brightness*g/255), (brightness*b/255));
}

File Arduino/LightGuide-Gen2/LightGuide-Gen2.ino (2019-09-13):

/* Arduino firmware for light pipetting guide v2 */
/* Scripps Florida                               */ 
/* Authors: Pierre Baillargeon and Kervin Coss   */
/* Correspondence: bpierre@scripps.edu           */ 
/* Date: 10/29/2018                              */ 

#include <FastLED.h>
#include "Adafruit_LiquidCrystal.h"

boolean newData = false;  //stores whether the program is presently receiving new data/input.
const byte numChars = 32; //determines the number of characters for the lists: receivedCharArray,tempStorage, rowLetter, and illuminationCommand
char receivedCharArray[numChars]; // Stores the character input received from the user

/* Components of command received over serial port - row, column and illumination command */ 
char rowLetter[numChars]= {0}; //Stores a single character, that is later used to determine the target row that the user wants to light-up
char plateBarcode[numChars];
int rowNumber;  //used to store the usable-index-number-value obtained with targetIndex, so that targetIndex can be reset to -1 so the convertRowLetterToNumber() keeps working
int columnNumber = 0; //Stores a single number, that is later used to determine the target column that the user wants to light-up
char illuminationCommand[numChars] = {0}; //Stores a single character, that is later used to determine whether the user wants to light-up a row, a column, or a single bulb 

/* Definition of I/O pin count for light guide in 384 well configuration */ 
const int numColumns = 24;
const int numRows = 16;
int pixelNumber;

CRGB leds[384];
Adafruit_LiquidCrystal lcd(0);

void setup() {
  
  FastLED.addLeds<NEOPIXEL, 6>(leds, 384); 
  
  Serial.begin(500000);
  /* Print instructions to serial port; useful for debugging or reminding users what the command format is */   
  Serial.println(F("Enter data the following format: <A,1,S,Barcode>"));
  Serial.println(F("First parameter is row letter, second parameter is column, third parameter is illumination command."));
  Serial.println(F("Valid row and columns are plate density dependent."));
  Serial.println(F("Valid illumination commands are: S - illuminate single well, R - illuminate entire row, C - illuminate entire column."));  
  Serial.println(); 

  
 // illuminationTest();
  clearDisplay();  

  // set up the LCD's number of rows and columns: 
  // Print a message to the LCD.
  lcd.begin(16, 2);  
  lcd.print(F("Barcode:"));
  lcd.setBacklight(HIGH);
  
}


void loop() {

  delay(100); // delay for 1/10 of a second
// 
  recvWithStartEndMarkers();
  
  if (newData == true) {
    /* Parse the data received over the serial port into its constituent parts [row, column, illumination command] */ 
    parseData();
    /* Return the parsed data back to the serial port - useful for debugging & confirmation to user */ 
    displayParsedCommand();
    /* Convert the row letter to a number */ 
    rowNumber = convertRowLetterToNumber(rowLetter);
    /* Clear the display from the previous command */     
    //clearDisplay();
    /* Execute the new command */ 
    parseIlluminationCommand(String(illuminationCommand));
    /* Set newData to false to indicate that we have processed this command */ 
    newData = false;
  }  
}

/* Receive incoming serial data and store in receivedCharArray array */ 
void recvWithStartEndMarkers() {
  static boolean recvInProgress = false;
  static byte indexListCounter = 0;
  char startMarker = '<';
  char endMarker = '>';
  char receivedCharacter;

  while (Serial.available() > 0 && newData == false) {
    receivedCharacter = Serial.read();
    if (recvInProgress == true) {
      if (receivedCharacter != endMarker) {
        receivedCharArray[indexListCounter] = receivedCharacter;
        indexListCounter++;
        if (indexListCounter >= numChars) {
          indexListCounter = numChars - 1;
        }
      }
      else {
        receivedCharArray[indexListCounter] = '\0'; // terminate the string
        recvInProgress = false;
        indexListCounter = 0;
        newData = true;
      }
    }
    else if (receivedCharacter == startMarker) {
      recvInProgress = true;
    }
  }
}

/* Parse incoming serial data */ 
void parseData() {      

    char * strtokIndx; // this is used by strtok() as an index
    strtokIndx = strtok(receivedCharArray,",");      // get the first part - the string
    strcpy(rowLetter, strtokIndx); // copy it to rowLetter       
    strtokIndx = strtok(NULL, ","); // this continues where the previous call left off
    columnNumber = atoi(strtokIndx);// convert this part to an integer    
    strtokIndx = strtok(NULL,",");      // get the first part - the string    
    strcpy(illuminationCommand, strtokIndx); // copy it to illuminationCommand
    strtokIndx = strtok(NULL,",");      // get the plate barcode
    strcpy(plateBarcode, strtokIndx); // copy it to illuminationCommand
}

/* Displays the parsed information to the serial terminal; useful for debugging communication issues */ 
void displayParsedCommand() {
    Serial.print(F("Column:"));
    Serial.println(columnNumber);
    Serial.print(F("Row:"));
    Serial.println(rowLetter);
    Serial.print(F("Command:"));
    Serial.println(illuminationCommand);    
    lcd.setCursor(0, 1);
    lcd.print(String(plateBarcode));
}

/* Turns off all LEDs */ 
void clearDisplay(){     
  FastLED.clear();
  FastLED.show();
  Serial.println(F("Display cleared."));    
} 

/* Turns on all LEDs for a given row */ 
void illuminateRow(int row){   
  Serial.print(F("Row:"));
  Serial.println(row);           
  for (int column=0;column<numColumns;column++){
    leds[24*row+column] = CRGB::White;        
    //Serial.println(24*row+column);
  }           
  //FastLED.show();
}

/* Turns on all LEDs for a given column */ 
void illuminateColumn(int column){       
  Serial.print(F("Column:"));
  Serial.println(column); 
  column=column-1;
  for(int row=0;row<numRows;row++) {
    leds[row*24+column] = CRGB::White;
    //Serial.println(row*24+column); 
  }           
  //FastLED.show();
}

/* Turns on an individual LED for a given row and column */ 
void illuminateWell(int c, int r){
  pixelNumber = (r)*numColumns+(c-1);
  Serial.print(F("Pixel #:"));
  Serial.println(pixelNumber);
  leds[pixelNumber] = CRGB::White;
  FastLED.show();           
}
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

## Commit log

2018-11-01 Initial commit
    Initial commit
    [30 degree Enclosure v2.1.stl, 30 degree RGB enclosure v2.1.stl, 384 well adapter board for Arduino mega.kicad_pcb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]
2018-11-12 Adding Neopixel based designs to repository
    [Neopixel mini - 96 well.kicad_pcb, Neopixel mini - 96 well.sch, Neopixel mini - 96 well.step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]
2019-03-26 Added fiducials and cleaned up silkscreen layer
    Added fiducial marks to four corners of board as recommended here: http://www.ladyada.net/library/pcb/fiducials.html
    Also cleaned up the silkscreen layer to properly identify pin 1 of each LED and clean up overlapping text.
    [Neopixel mini - 96 well.kicad_pcb]
2019-03-26 Corrected error on silkscreen
    Location for identification text for C58 was not updated in prior update. It is corrected now.
    [Neopixel mini - 96 well.kicad_pcb]
2019-03-26 Updated C58 reference on silkscreen
    Missed C58 reference correction on previous update. It is now in the correct location.
    [Neopixel mini - 96 well.kicad_pcb]
2019-04-05 Update readme
    Added sample images of 96 and 384 well RGB light guide illumination panels
2019-05-19 Updated to v1.3
    Updated to v1.3. Changes:
    - Removed HCC Module footprint from back to simplify design
    - Added copper pour to front of PCB for +5V
    - Added fiducials for pick and place automation support
    [Neopixel mini - 96 well.kicad_pcb, Neopixel mini - 96 well.sch]
2019-05-19 Updated to v1.1
    Updated to v1.1. Changes:
    - Removed HCC module footprint from back to simplify design
    - Added fiducuals for pick and place automation
    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
    [Neopixel nano - 384 well.kicad_pcb]
2019-06-01 Adding updated photo of v1.3 PCB
    Added updated photo of 96 well RGB light guide - v1.3
2019-06-01 Updated Readme
    Updated readme to show latest version of 96 well light guide PCB
2019-06-08 Created example Arduino code for light panel
    This sample code turns all LEDs of the 96 or 384 well light panel on in a repeating sequence of red, green and blue.
2019-06-10 Create 96-well-rgb-light-guide-wiring-example.png
    Added wiring example for 96 well RGB light guide with light panel power board
2019-06-10 Added Fritzing files
    Added Fritzing part files for 96 well RGB light guide and light panel. Also added example wiring diagram for typical 5V microcontroller.
    [96 well RGB panel wiring example.fzz]
2019-06-24 Updating PCB images for documentation
    New images of 384 and 96 well light guides for better documentation
2019-06-24 Updated sample image of 384 well PCB
    Latest version is example of PCB assembled by Small Batch Assembly
2019-07-09 Added support for 384 well light panel
    Added support for 384 well light panel to existing code; user can switch between 96 or 384 by using the NUM_LEDS variable.
2019-08-29 Initial commit for serial dilution program
    Adding serial dilution sample application to repository.
2021-08-12 Example CAD file addition
    Adding CAD files for portable enclosure example.
    [Battery lid.stl, Enclosure top lid.stl, Enclosure.stl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]
